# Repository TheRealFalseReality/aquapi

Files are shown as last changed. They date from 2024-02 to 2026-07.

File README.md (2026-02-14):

# [AquaPi for ESPHome](./)
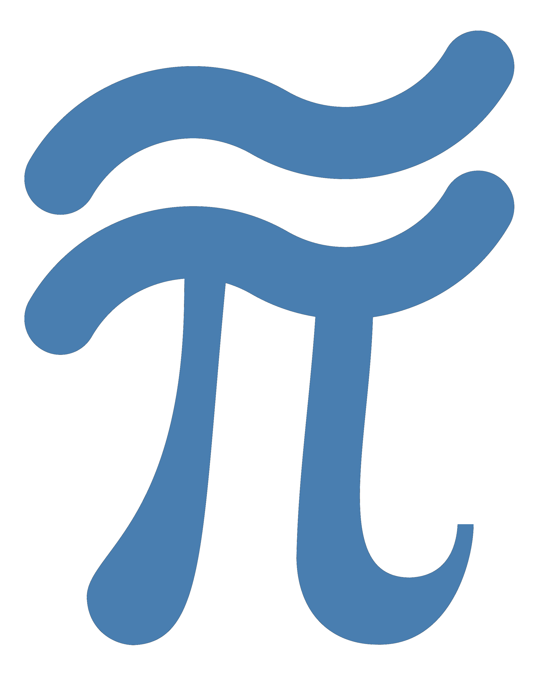
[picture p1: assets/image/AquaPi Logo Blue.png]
AquaPi Logo


The Aquarium meets the Smart Home! AquaPi brings powerful monitoring and automation to your aquarium setup using affordable [ESPHome](https://esphome.io/) devices and [Home Assistant](https://www.home-assistant.io/).  

**Open-source:** Freely accessible for anyone to use, modify, and contribute.  
**Modular and Customizable:** Expand the system to fit your specific needs and preferences.  
**Affordable:** A budget-friendly alternative to high-end monitoring solutions without compromising functionality.  
**Versatile:** Monitor and automate a wide range of vital water parameters such as pH, salinity, dissolved oxygen, and more.  

---

### **Quick Links**
- **[Install](https://therealfalsereality.github.io/aquapi/):** Navigate via the link, scroll to `Connect` to install via ESPHopme Web or use releases to install manually.
- **[Setup Guide](https://github.com/TheRealFalseReality/aquapi/wiki/Setup-AquaPi):** Start here for step-by-step instructions.
- **[Build It Yourself](https://github.com/TheRealFalseReality/aquapi/wiki/Build-It-Yourself-&-Spare-Parts):** Parts list and assembly guide.
- **[In-Depth Wiki](https://github.com/TheRealFalseReality/aquapi/wiki):** Calibration, sensor info, circuit diagrams, and more.
- **[Join the Discussion!](https://www.reef2reef.com/threads/aquapi-an-open-souce-aquarium-controller.1033171/)** Participate in the Reef2Reef forums!
- **[Buy AquaPi Now!](https://www.capitalcityaquatics.com/store/aquapi)** Purchase complete builds or modular components.

---

## Why AquaPi?

---

## Demo
## [**Try out the AquaPi Demo!**](https://aquapi.thefalsehome.duckdns.org/dashboard-aquariums)

<table>
  <tr>
    <td>
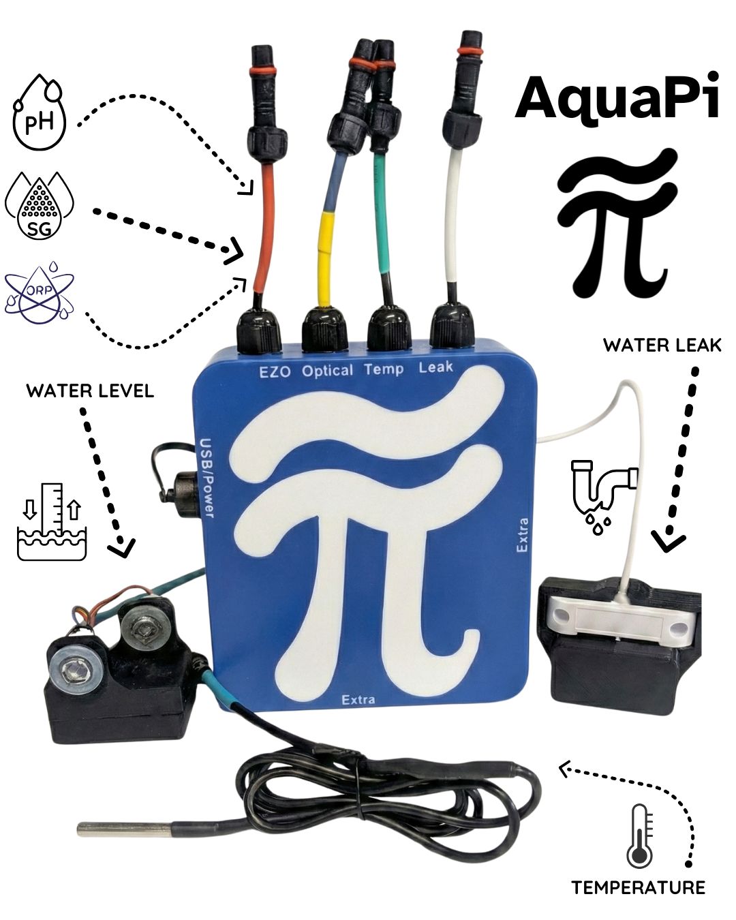
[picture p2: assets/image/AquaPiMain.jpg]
AquaPi Device
      
    </td>
    <td>
      AquaPi Setup Image
    </td>
  </tr>
</table>

---

## Key Features

- Comprehensive monitoring for **temperature**, **pH**, **salinity**, **dissolved oxygen**, and more using affordable Atlas Scientific EZO circuits.
- Seamless integration with **ESPHome** and **Home Assistant** for robust automation, visualization, and control.
- Expandable system to add new sensors, actuators, and custom automations tailored to your aquarium.

---

## Hardware Requirements

- **ESP32 DevKit:** A versatile microcontroller to power AquaPi.
- **Home Assistant Device:** A Raspberry Pi 3 or higher is recommended (the more RAM, the better).
  - Setup Home Assistant on your Raspberry Pi: [Get Raspberry Pi Imager](https://www.raspberrypi.com/software/)
- **Power Supply:** A reliable 5V 3A power source.

### Supported Sensors and Probes
#### **Temperature (Dallas DS18B20):**
- Waterproof thermistor capable of supporting multiple probes using an index-based configuration.
- [**Temperature Sensor Wiki**](https://github.com/TheRealFalseReality/aquapi/wiki/Dallas-Temperature-Sensor)

#### **Water Level:**
- Optical infrared liquid sensors with magnetic mounts.

#### **Water Leak Sensor:**
- Detects leaks with liquid detection sensors and magnetic mounting for flexibility.

#### **pH Monitoring (EZO-pH):**
- High-accuracy pH measurements with the EZO pH circuit, ISO 10523 compliant.  
- **Range:** 0-14 pH  
- **Recalibration Interval:** 1 year  
- **Probe Life Expectancy:** ~2.5+ years  
- [**pH Datasheet**](https://files.atlas-scientific.com/pH_EZO_Datasheet.pdf)

#### **Salinity Conductivity (EZO-EC):**
- Measures conductivity, TDS, salinity, and specific gravity with EZO EC circuit, ISO 7888 compliant.  
- **Range:** 0.07−500,000+ μS/cm  
- **Recalibration Interval:** ~10 years  
- **Probe Life Expectancy:** ~10 years  
- [**EC Datasheet**](https://files.atlas-scientific.com/EC_EZO_Datasheet.pdf)

#### **Dissolved Oxygen Monitoring (EZO-DO):**
- Accurate dissolved oxygen monitoring, suitable for many environments.  
- **Range:** 0.00-100 mg/L (0-350% saturation)  
- **Probe Life Expectancy:** ~4 years  
- [**DO Datasheet**](https://files.atlas-scientific.com/DO_EZO_Datasheet.pdf)

#### **Oxidation-Reduction Potential (EZO-ORP):**
- Measures the oxidation or reduction potential state in water.  
- **Range:** -2000mV to +2000mV  
- **Probe Life Expectancy:** ~2 years  
- [**ORP Datasheet**](https://files.atlas-scientific.com/ORP_EZO_Datasheet.pdf)

#### **Peristaltic Dosing Pump (EZO-PMP):**
- Dispenses liquids accurately for chemical or nutrient dosing.  
- **Flow Rate:** 0.5ml to 105ml/min  
- **Tube Size:** 5mm  
- **Head Height:** 8.1m (26.5')  
- [**Peristaltic Pump Datasheet**](https://files.atlas-scientific.com/EZO_PMP_Datasheet.pdf)

#### **Carbon Dioxide Air Monitoring (EZO-CO2):**
- Measures gaseous CO2 concentration.  
- **Range:** 0−10,000 ppm  
- **Life Expectancy:** ~5.5 years  
- [**CO2 Datasheet**](https://files.atlas-scientific.com/EZO_CO2_Datasheet.pdf)

### Additional Supported Sensors
- **Humidity:** [EZO-HUM Datasheet](https://files.atlas-scientific.com/EZO-HUM-Datasheet.pdf)  
- **RTD Temperature:** [EZO-RTD Datasheet](https://files.atlas-scientific.com/EZO_RTD_Datasheet.pdf)

### Circuit Diagram
For a detailed circuit diagram and wiring instructions, visit the [Wiki Circuit Page](https://github.com/TheRealFalseReality/aquapi/wiki/Circuit).

---

## Installation and Setup
### Setup Your Devices:
Follow the **[Setup Guide](https://github.com/TheRealFalseReality/aquapi/wiki/Setup-AquaPi)** for detailed step-by-step instructions for configuring your ESP32, connecting your sensors, and running AquaPi.

### Update Wirelessly:
Keep your AquaPi firmware up-to-date with **ESPHome** using the built-in Over-the-Air (OTA) update functionality. For details, see the [Update Guide](https://github.com/TheRealFalseReality/aquapi/wiki/Setup-AquaPi#update).

### Web Server Access:
Optionally, you can access AquaPi's web server for managing the device without Home Assistant. See the [Web Server Guide](https://github.com/TheRealFalseReality/aquapi/wiki/Setup-AquaPi#update) for more details.

---

## Expand and Customize AquaPi
AquaPi's modular design can be customized and expanded to meet your specific needs. For advanced configurations, see:  
- **[Blueprints](https://github.com/TheRealFalseReality/aquapi/wiki/Blueprints):** Automations to control other smart devices in Home Assistant.  
- **[Substitutions](https://github.com/TheRealFalseReality/aquapi/wiki/Substitutions):** Custom configuration variables for your specific setup.

---

## AquaPi AI: Your Intelligent Aquarium Assistant 🐠
### **[AquaPi AI](https://therealfalsereality.github.io/):** Level up your aquarium with AI!  
- **AI Compatibility Calculator:** Check fish compatibility instantly.  
- **Care Guides & Recommendations:** Get expert tank advice.  
- **Automation Scripts & Photo Analysis:** Automate your aquarium and analyze photos for optimized care.  

---

## Get Started Today!
- Check out the **[Setup Guide](https://github.com/TheRealFalseReality/aquapi/wiki/Setup-AquaPi)** to start using AquaPi.
- Enhance your aquarium monitoring with AquaPi’s powerful open-source, modular system!

---

made-for-esphome-white-on-black

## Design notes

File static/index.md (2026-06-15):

AquaPi Logo

The Aquarium meets the Smart Home! AquaPi brings powerful monitoring and automation to your aquarium setup using affordable [ESPHome](https://esphome.io/) devices and [Home Assistant](https://www.home-assistant.io/).  

**Open-source:** Freely accessible for anyone to use, modify, and contribute.  
**Modular and Customizable:** Expand the system to fit your specific needs and preferences.  
**Affordable:** A budget-friendly alternative to high-end monitoring solutions without compromising functionality.  
**Versatile:** Monitor and automate a wide range of vital water parameters such as pH, salinity, dissolved oxygen, and more.  

---

### **Quick Links**
- **[Setup Guide](https://github.com/TheRealFalseReality/aquapi/wiki/Setup-AquaPi):** Start here for step-by-step instructions.
- **[Build It Yourself](https://github.com/TheRealFalseReality/aquapi/wiki/Build-It-Yourself-&-Spare-Parts):** Parts list and assembly guide.
- **[In-Depth Wiki](https://github.com/TheRealFalseReality/aquapi/wiki):** Calibration, sensor info, circuit diagrams, and more.
- **[Join the Discussion!](https://www.reef2reef.com/threads/aquapi-an-open-souce-aquarium-controller.1033171/)** Participate in the Reef2Reef forums!
- **[Buy AquaPi Now!](https://www.capitalcityaquatics.com/store/aquapi)** Purchase complete builds or modular components.

---

## Why AquaPi?

---

## Demo
[**Try out the AquaPi Demo!**](https://www.capitalcityaquatics.com/store#storelivedemo)

<table>
  <tr>
    <td>
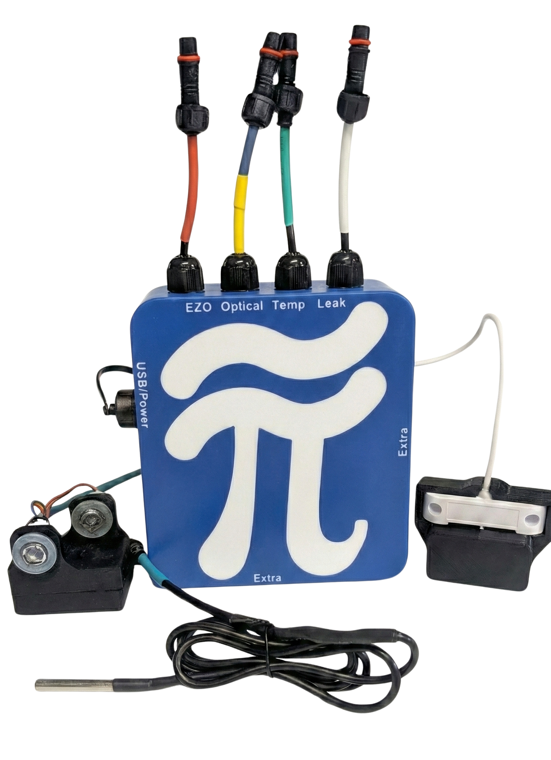
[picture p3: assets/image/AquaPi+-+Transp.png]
AquaPi Device
      
    </td>
    <td>
      AquaPi Setup Image
    </td>
  </tr>
</table>

---

## Install
**You can typically skip this as AquaPi comes pre-installed!**  
Use the button below to install the pre-built firmware directly to your device via USB from the browser.

### AquaPi Standard *(Inverted Optical - Legacy Optical Sensors)*
<esp-web-install-button manifest="firmware/aquapi-standard.manifest.json"></esp-web-install-button>

### AquaPi Optical *(Non-Inverted Optical - Newer Optical Sensors)*
<esp-web-install-button manifest="firmware/aquapi-standard.manifest.json"></esp-web-install-button>

<script type="module" src="https://unpkg.com/esp-web-tools@9.1.0/dist/web/install-button.js?module"></script>  

## Key Features

- Comprehensive monitoring for **temperature**, **pH**, **salinity**, **dissolved oxygen**, and more using affordable Atlas Scientific EZO circuits.
- Seamless integration with **ESPHome** and **Home Assistant** for robust automation, visualization, and control.
- Expandable system to add new sensors, actuators, and custom automations tailored to your aquarium.

---

## Hardware Requirements

- **ESP32 DevKit:** A versatile microcontroller to power AquaPi.
- **Home Assistant Device:** A Raspberry Pi 3 or higher is recommended (the more RAM, the better).
  - Setup Home Assistant on your Raspberry Pi: [Get Raspberry Pi Imager](https://www.raspberrypi.com/software/)
- **Power Supply:** A reliable 5V 3A power source.

### Supported Sensors and Probes
#### **Temperature (Dallas DS18B20):**
- Waterproof thermistor capable of supporting multiple probes using an index-based configuration.
- [**Temperature Sensor Wiki**](https://github.com/TheRealFalseReality/aquapi/wiki/Dallas-Temperature-Sensor)

#### **Water Level:**
- Optical infrared liquid sensors with magnetic mounts.

#### **Water Leak Sensor:**
- Detects leaks with liquid detection sensors and magnetic mounting for flexibility.

#### **pH Monitoring (EZO-pH):**
- High-accuracy pH measurements with the EZO pH circuit, ISO 10523 compliant.  
- **Range:** 0-14 pH  
- **Recalibration Interval:** 1 year  
- **Probe Life Expectancy:** ~2.5+ years  
- [**pH Datasheet**](https://files.atlas-scientific.com/pH_EZO_Datasheet.pdf)

#### **Salinity Conductivity (EZO-EC):**
- Measures conductivity, TDS, salinity, and specific gravity with EZO EC circuit, ISO 7888 compliant.  
- **Range:** 0.07−500,000+ μS/cm  
- **Recalibration Interval:** ~10 years  
- **Probe Life Expectancy:** ~10 years  
- [**EC Datasheet**](https://files.atlas-scientific.com/EC_EZO_Datasheet.pdf)

#### **Dissolved Oxygen Monitoring (EZO-DO):**
- Accurate dissolved oxygen monitoring, suitable for many environments.  
- **Range:** 0.00-100 mg/L (0-350% saturation)  
- **Probe Life Expectancy:** ~4 years  
- [**DO Datasheet**](https://files.atlas-scientific.com/DO_EZO_Datasheet.pdf)

#### **Oxidation-Reduction Potential (EZO-ORP):**
- Measures the oxidation or reduction potential state in water.  
- **Range:** -2000mV to +2000mV  
- **Probe Life Expectancy:** ~2 years  
- [**ORP Datasheet**](https://files.atlas-scientific.com/ORP_EZO_Datasheet.pdf)

#### **Peristaltic Dosing Pump (EZO-PMP):**
- Dispenses liquids accurately for chemical or nutrient dosing.  
- **Flow Rate:** 0.5ml to 105ml/min  
- **Tube Size:** 5mm  
- **Head Height:** 8.1m (26.5')  
- [**Peristaltic Pump Datasheet**](https://files.atlas-scientific.com/EZO_PMP_Datasheet.pdf)

#### **Carbon Dioxide Air Monitoring (EZO-CO2):**
- Measures gaseous CO2 concentration.  
- **Range:** 0−10,000 ppm  
- **Life Expectancy:** ~5.5 years  
- [**CO2 Datasheet**](https://files.atlas-scientific.com/EZO_CO2_Datasheet.pdf)

### Additional Supported Sensors
- **Humidity:** [EZO-HUM Datasheet](https://files.atlas-scientific.com/EZO-HUM-Datasheet.pdf)  
- **RTD Temperature:** [EZO-RTD Datasheet](https://files.atlas-scientific.com/EZO_RTD_Datasheet.pdf)

### Circuit Diagram
For a detailed circuit diagram and wiring instructions, visit the [Wiki Circuit Page](https://github.com/TheRealFalseReality/aquapi/wiki/Circuit).

---

## Installation and Setup
### Setup Your Devices:
Follow the **[Setup Guide](https://github.com/TheRealFalseReality/aquapi/wiki/Setup-AquaPi)** for detailed step-by-step instructions for configuring your ESP32, connecting your sensors, and running AquaPi.

### Update Wirelessly:
Keep your AquaPi firmware up-to-date with **ESPHome** using the built-in Over-the-Air (OTA) update functionality. For details, see the [Update Guide](https://github.com/TheRealFalseReality/aquapi/wiki/Setup-AquaPi#update).

### Web Server Access:
Optionally, you can access AquaPi's web server for managing the device without Home Assistant. See the [Web Server Guide](https://github.com/TheRealFalseReality/aquapi/wiki/Setup-AquaPi#update) for more details.

---

## Expand and Customize AquaPi
AquaPi's modular design can be customized and expanded to meet your specific needs. For advanced configurations, see:  
- **[Blueprints](https://github.com/TheRealFalseReality/aquapi/wiki/Blueprints):** Automations to control other smart devices in Home Assistant.  
- **[Substitutions](https://github.com/TheRealFalseReality/aquapi/wiki/Substitutions):** Custom configuration variables for your specific setup.

---

## AquaPi AI: Your Intelligent Aquarium Assistant 🐠
### **[AquaPi AI](https://therealfalsereality.github.io/):** Level up your aquarium with AI!  
- **AI Compatibility Calculator:** Check fish compatibility instantly.  
- **Care Guides & Recommendations:** Get expert tank advice.  
- **Automation Scripts & Photo Analysis:** Automate your aquarium and analyze photos for optimized care.  

---

## Get Started Today!
- Check out the **[Setup Guide](https://github.com/TheRealFalseReality/aquapi/wiki/Setup-AquaPi)** to start using AquaPi.
- Enhance your aquarium monitoring with AquaPi’s powerful open-source, modular system!

---

made-for-esphome-white-on-black

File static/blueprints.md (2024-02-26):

---
layout: page
title: Blueprints
permalink: /blueprints/
---
## [Blueprint Wiki](https://github.com/TheRealFalseReality/aquapi/wiki/Blueprints)
Click the link above to explore my Home Assistant scripts and automations for smart device control! I cover everything from lighting to water level management.  

### [Join the Community](https://community.home-assistant.io/u/therealfalsereality/activity/topics) to discuss improvements or make suggestions!

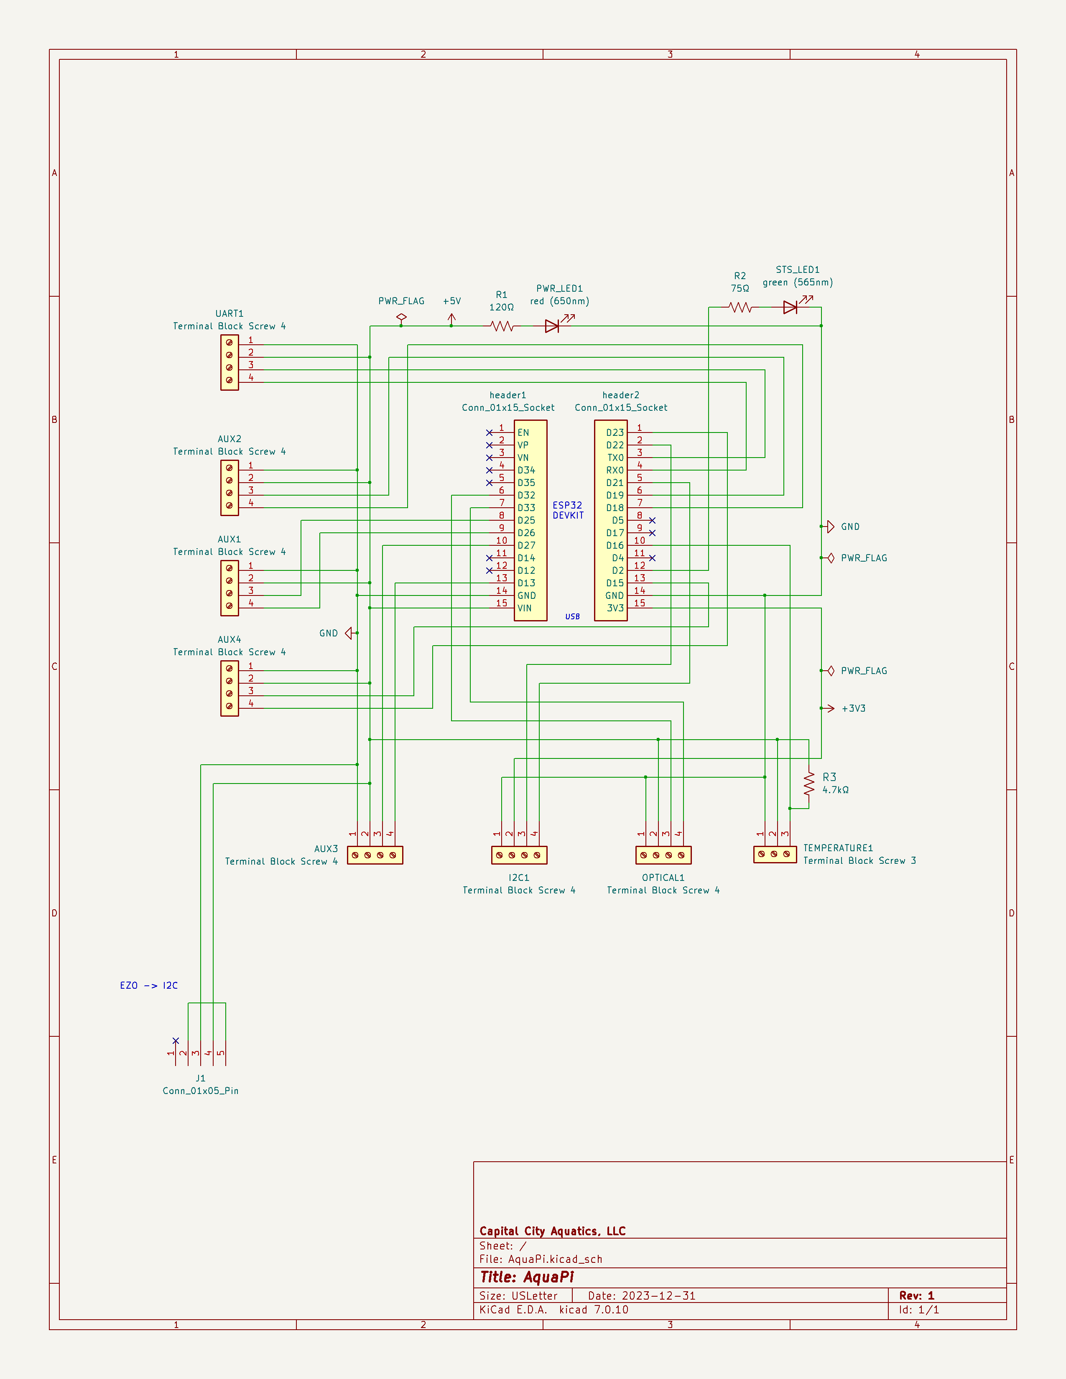
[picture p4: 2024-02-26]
assets/image/Schematic.png

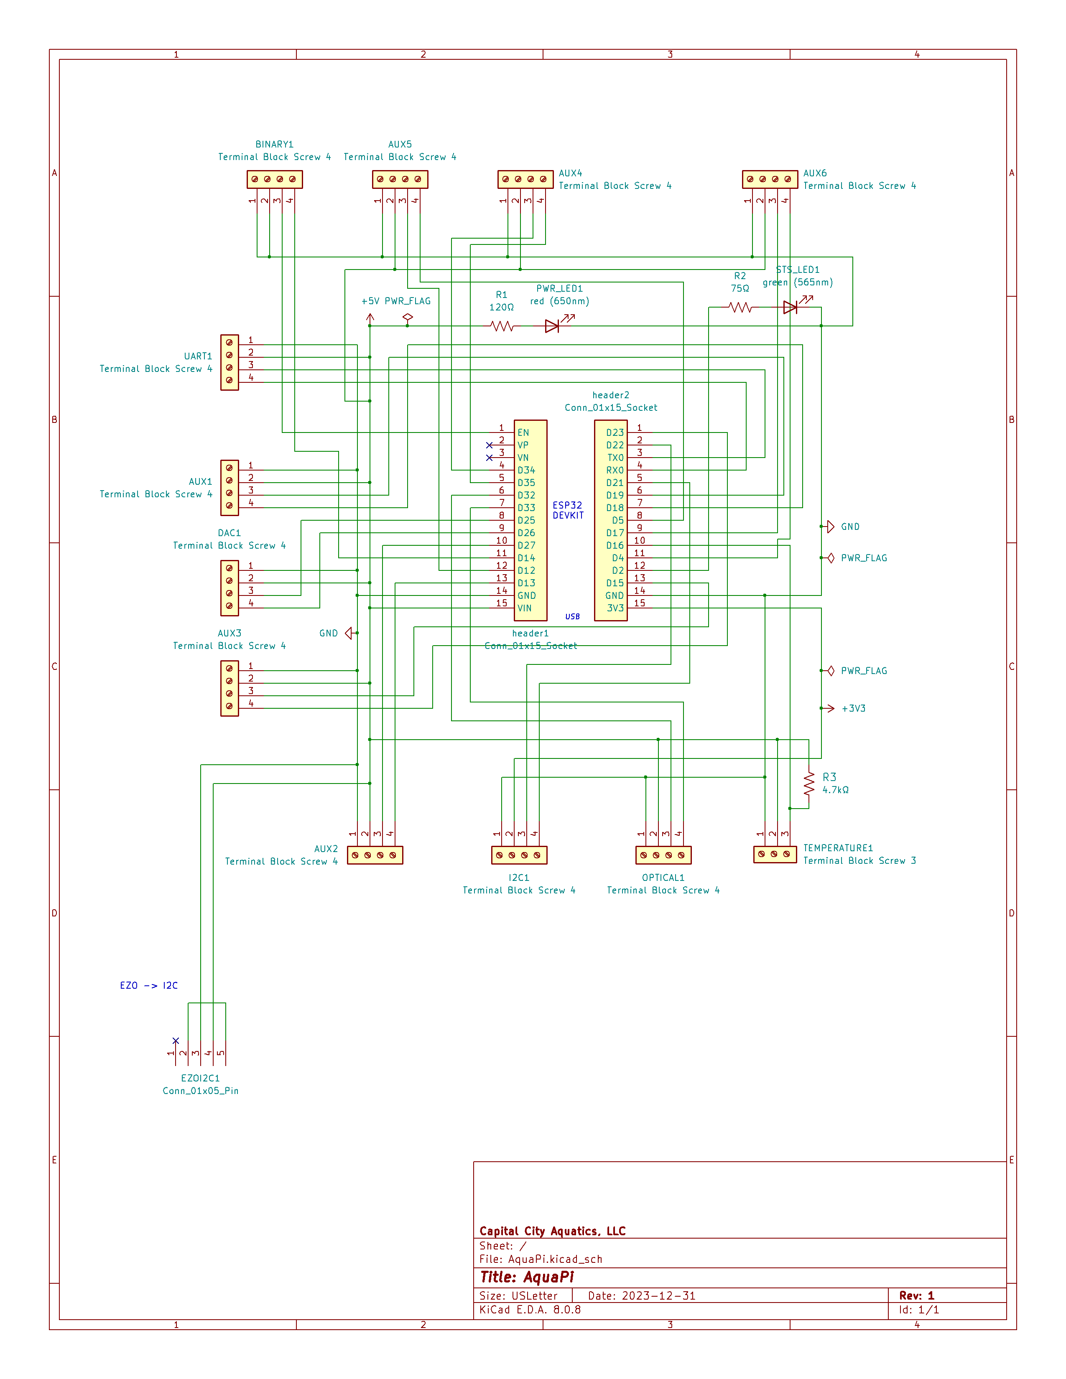
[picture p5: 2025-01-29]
assets/image/Schematicv2.png

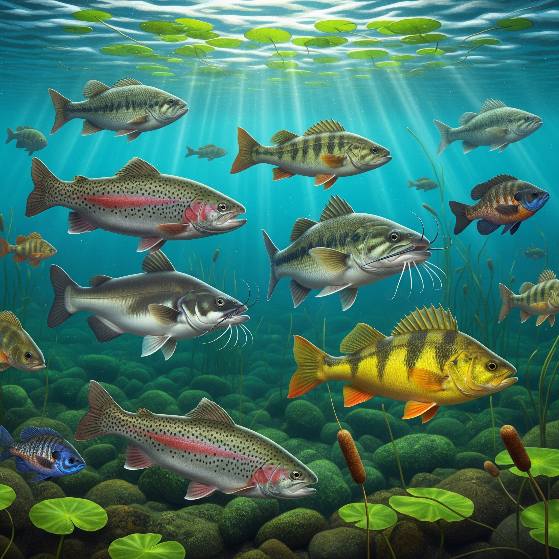
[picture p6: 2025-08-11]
assets/image/Gemini_Generated_Image_valg19valg19valg.jpg

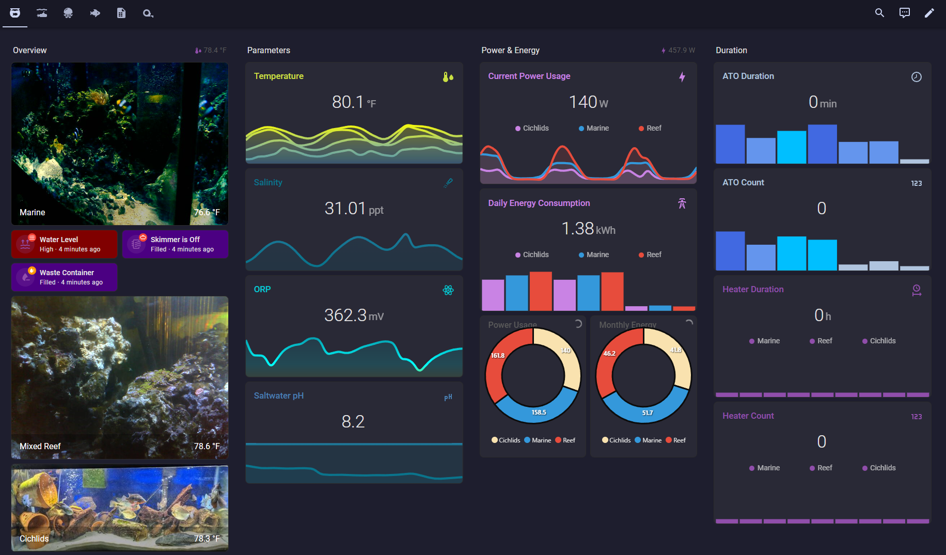
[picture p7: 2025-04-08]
assets/image/Screenshot 2024-10-15 120850.png

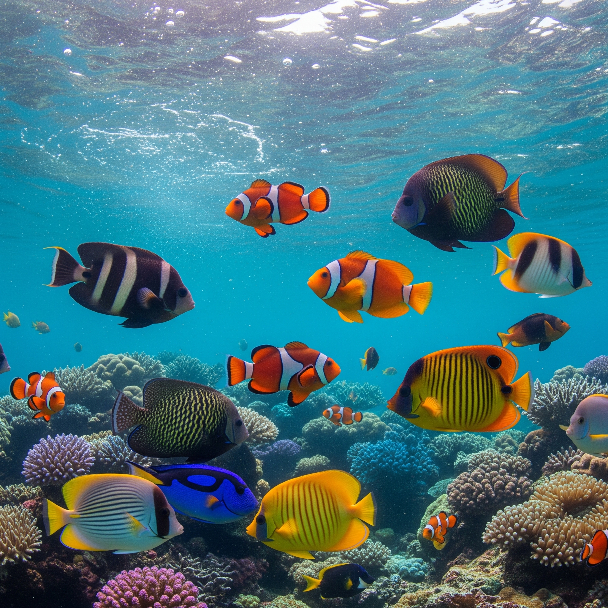
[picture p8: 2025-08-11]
assets/image/Gemini_Generated_Image_w0boutw0boutw0bo.jpg

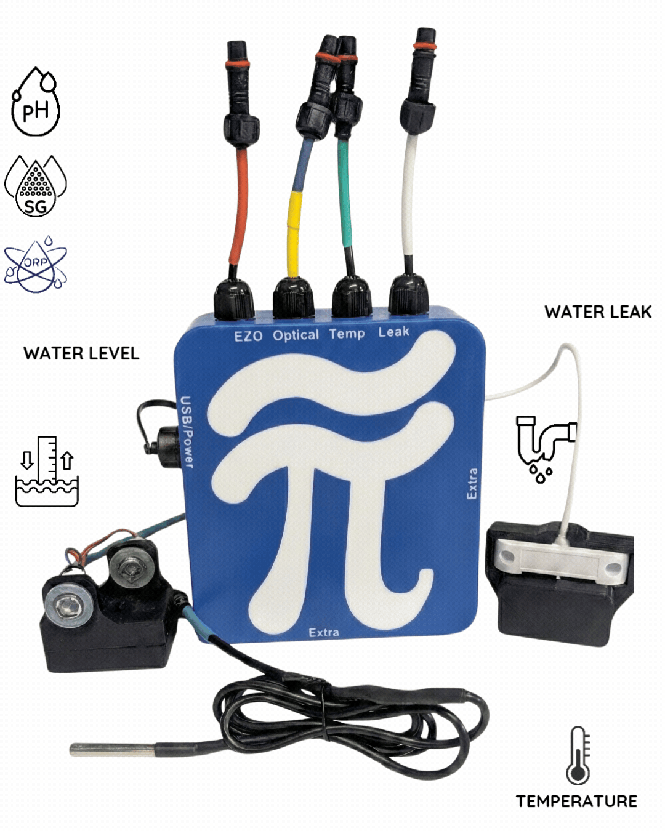
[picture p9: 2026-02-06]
assets/image/AquaPiMain.gif

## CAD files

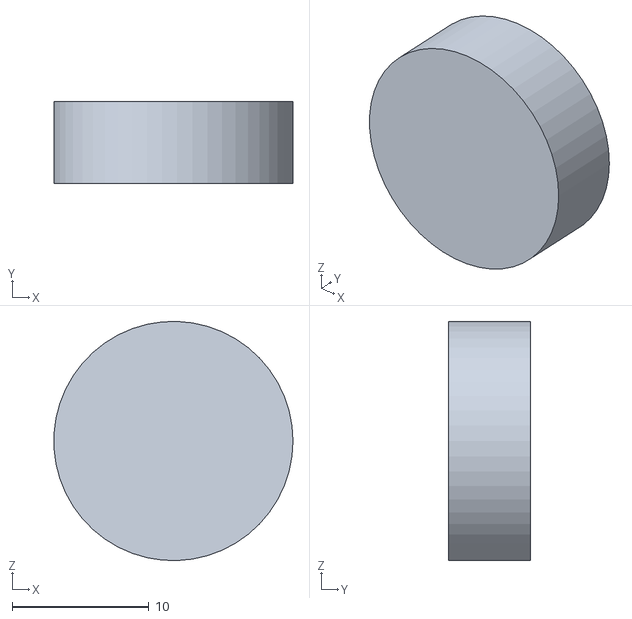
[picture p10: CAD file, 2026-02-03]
assets/STLModels/AquaPiCase/AquaPi Case - Plug2.stl
17.5 x 6.00 x 17.5

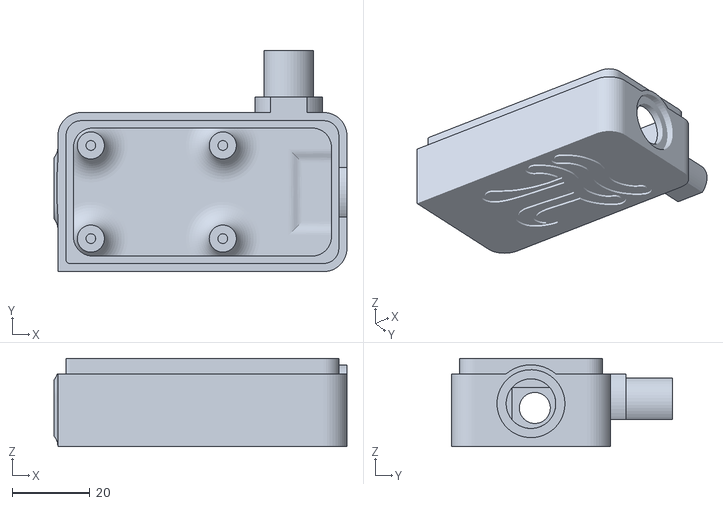
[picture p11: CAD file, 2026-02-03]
assets/STLModels/EZOCase/EZOBoard Case rev2 v11.stl
75.5 x 57.0 x 22.8

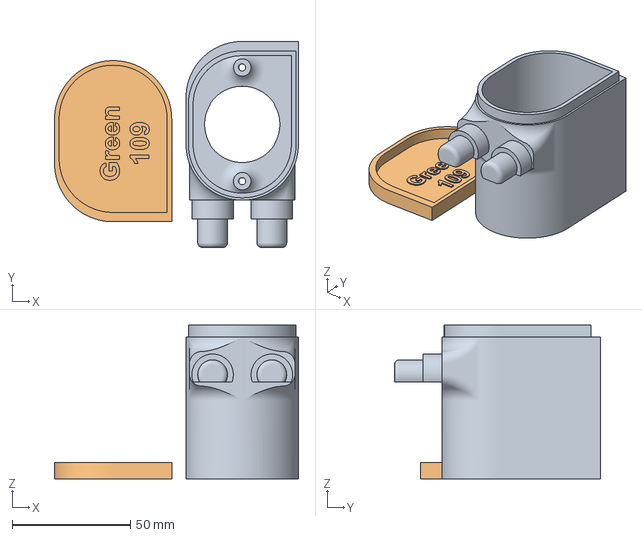
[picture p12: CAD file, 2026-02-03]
assets/STLModels/EZOPump/AquaPi Pump Case - Green.3mf
103.0 x 87.0 x 65.0 mm
AquaPi Pump Case v25.stl
AquaPi Pump Lid v25.stl

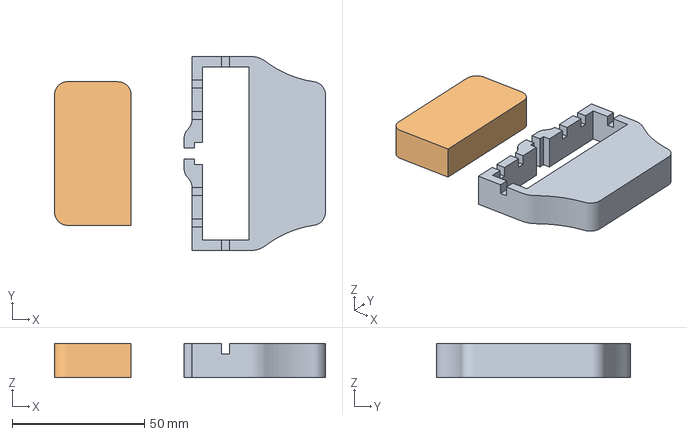
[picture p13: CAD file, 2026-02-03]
assets/STLModels/LeakSensor/Leak Sensor - Mount.3mf
102.5 x 73.5 x 13.0 mm
Leak Sensor v14 - Base.stl
Leak Sensor - Mag v13.stl

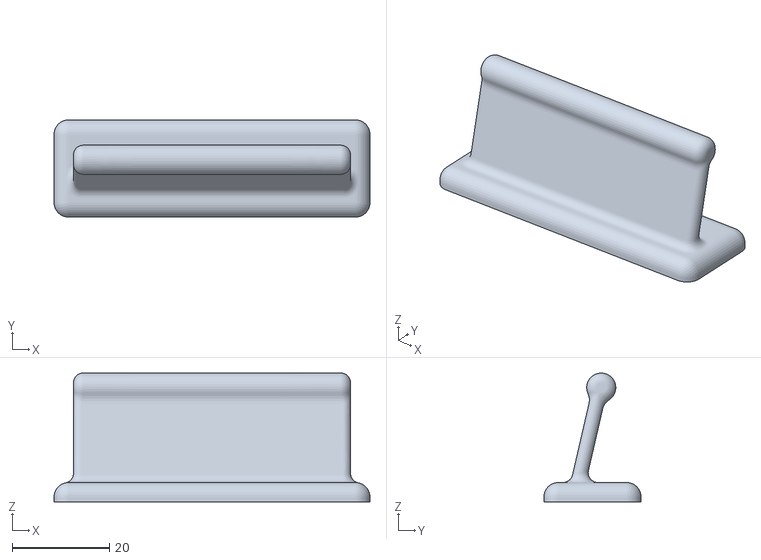
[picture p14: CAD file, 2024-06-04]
assets/STLModels/misc/Handle v2.stl
65.0 x 20.0 x 26.5

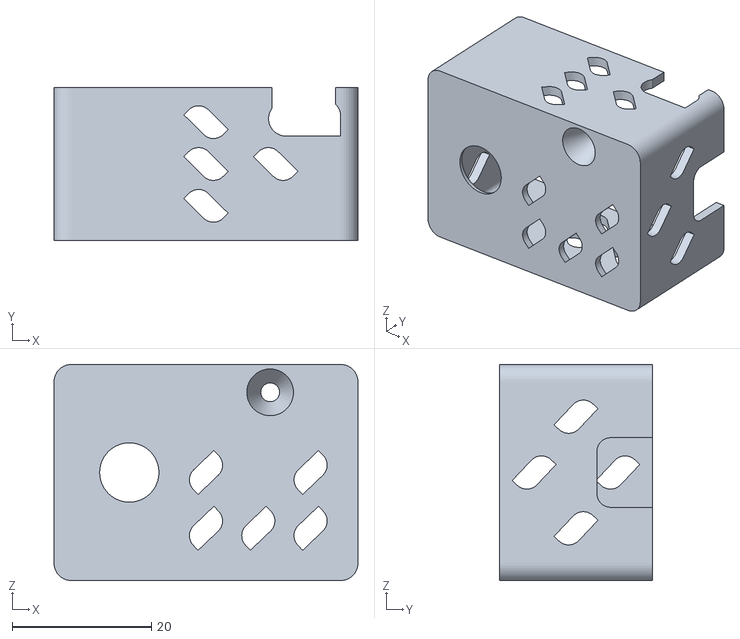
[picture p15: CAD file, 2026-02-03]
assets/STLModels/SnapCam/esp32Cam - Case v35.stl
43.6 x 22.0 x 31.0

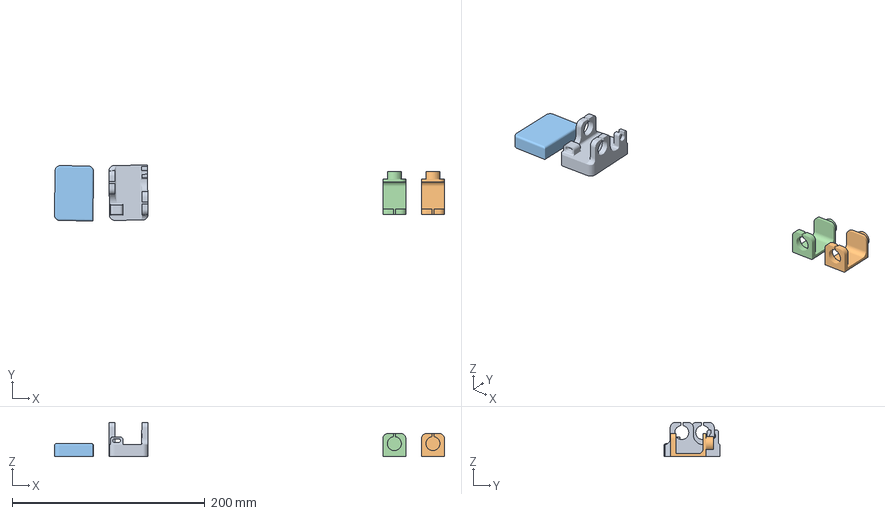
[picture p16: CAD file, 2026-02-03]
assets/STLModels/WaterLevelBracket/WaterLevelHolder.3mf
404.5 x 57.9 x 35.5 mm
OpticalBracket_Holder.stl
OpticalBracket Extender.stl x 2
OpticalBracket_Back.stl

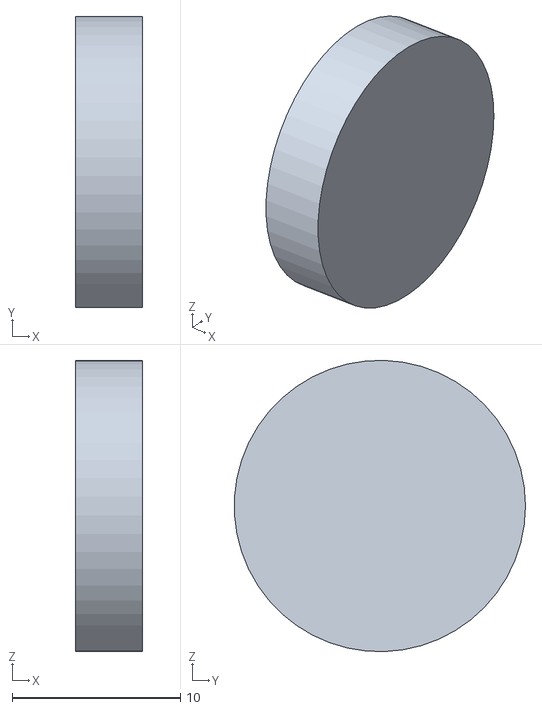
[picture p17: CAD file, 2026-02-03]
assets/STLModels/AquaPiCase/AquaPi Case - Plug1.stl
4.00 x 17.3 x 17.3

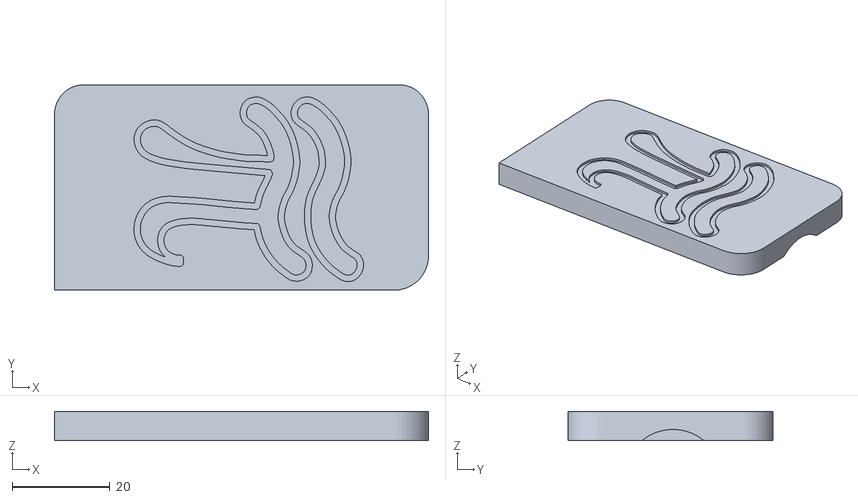
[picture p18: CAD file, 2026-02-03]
assets/STLModels/EZOCase/EZOBoard Lid rev2 v14.stl
76.5 x 42.0 x 6.00

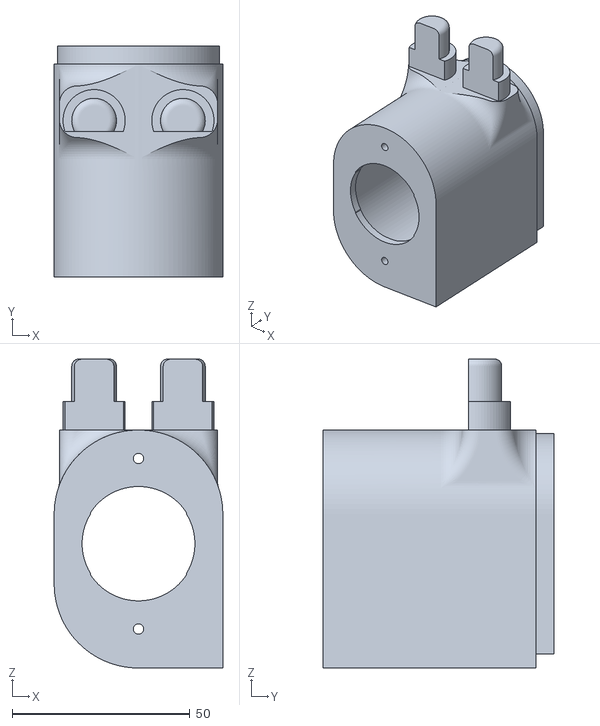
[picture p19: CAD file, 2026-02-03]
assets/STLModels/EZOPump/AquaPi Pump Case v25.stl
47.5 x 65.0 x 87.0

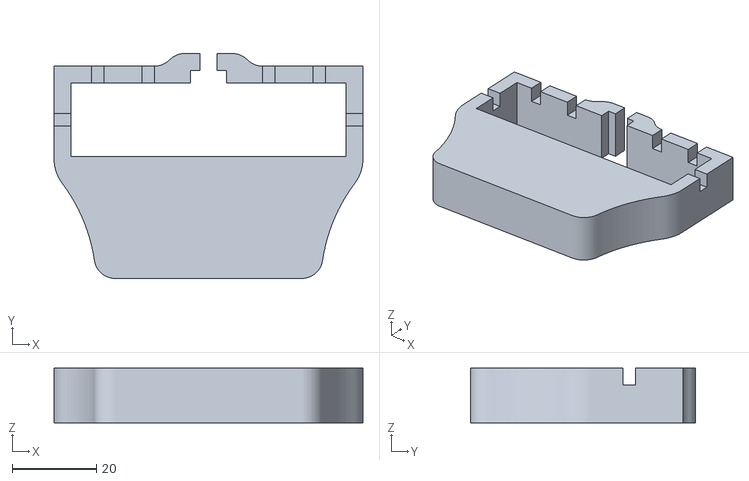
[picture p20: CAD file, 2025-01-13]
assets/STLModels/LeakSensor/Leak Sensor v14 - Base.stl
73.5 x 53.5 x 13.0

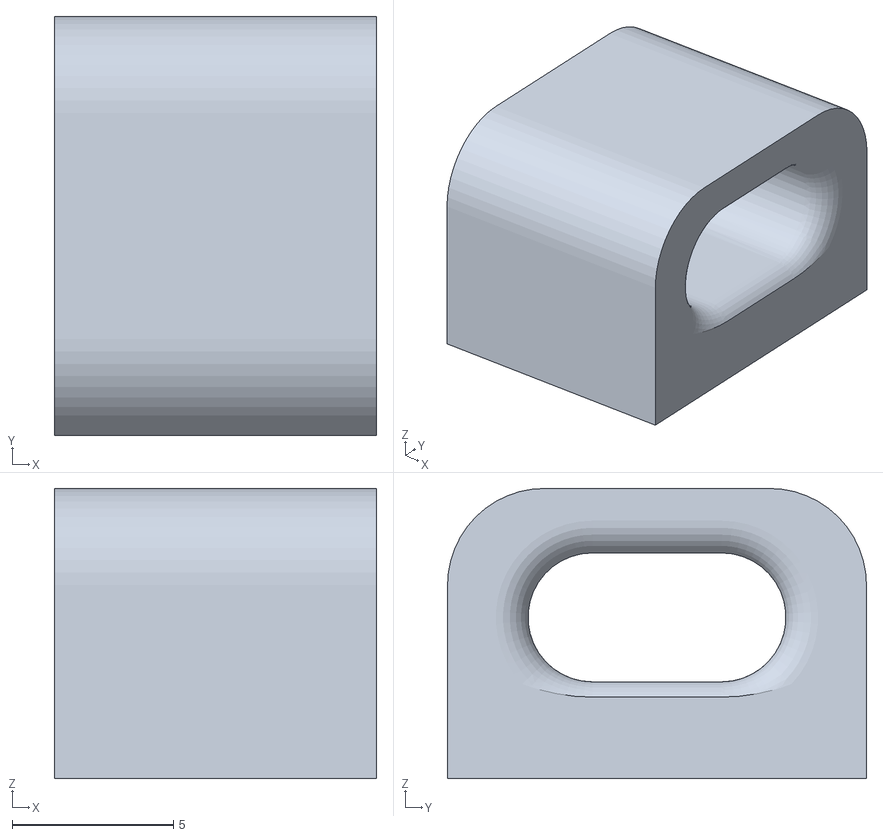
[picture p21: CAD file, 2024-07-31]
assets/STLModels/SnapCam/BallMount - ZipTie v9.stl
10.0 x 13.0 x 9.00

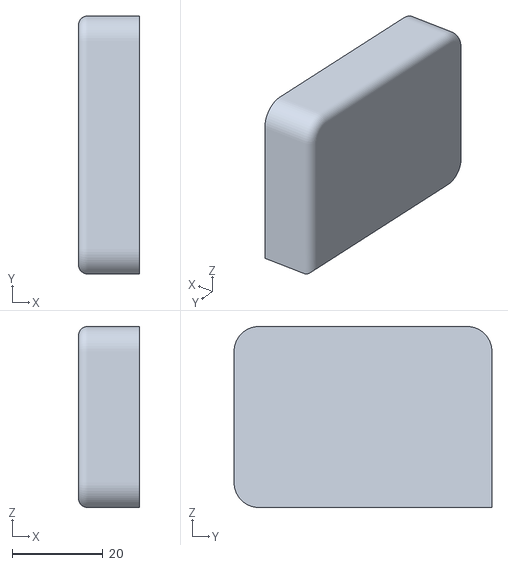
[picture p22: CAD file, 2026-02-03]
assets/STLModels/WaterLevelBracket/OpticalBracket_Back.stl
13.5 x 57.0 x 40.0

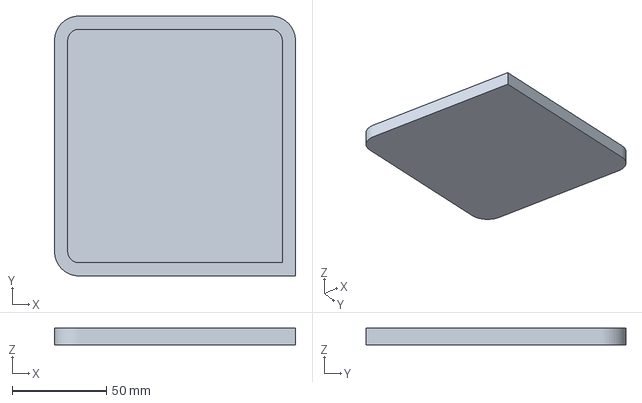
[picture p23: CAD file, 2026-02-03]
assets/STLModels/AquaPiCase/AquaPi Case - Lid MC.3mf
128.0 x 138.0 x 9.00 mm

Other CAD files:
assets/STLModels/EZOCase/EZOBoard rev2.3mf
assets/STLModels/EZOPump/AquaPi Pump Case - Red.3mf
assets/STLModels/LeakSensor/Leak Sensor - Mag v13.stl
assets/STLModels/SnapCam/BallMount v9.stl
assets/STLModels/AquaPiCase/AquaPi Case - Base v58.stl
assets/STLModels/AquaPiCase/AquaPi Case - Lid v45.stl
assets/STLModels/AquaPiCase/AquaPi Mount - Base v25.stl
assets/STLModels/AquaPiCase/AquaPi Mount - Hanger v25.stl
assets/STLModels/EZOPump/AquaPi Pump Lid - Green v25.stl
assets/STLModels/EZOPump/AquaPi Pump Lid - Red v26.stl
assets/STLModels/SnapCam/esp32Cam - Lid v32.stl
assets/STLModels/WaterLevelBracket/OpticalBracket Extender.stl
assets/STLModels/WaterLevelBracket/OpticalBracket_Holder.stl

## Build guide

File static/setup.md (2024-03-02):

---
layout: page
title: Setup
permalink: /setup/
---
## Install
**You can typically skip this as AquaPi comes pre-installed!**  

### Easy
Go back to [**Home**](https://therealfalsereality.github.io/aquapi/) and scroll down to ***Install*** and click the ***Connect*** button.  

### Releases .bin
1. Download latest .bin from [**Releases**](https://github.com/TheRealFalseReality/aquapi/releases)  
2. Install via [**ESPHome - Web**](https://web.esphome.io/)  

## Setup AquaPi
Follow link below for guide:  
<a href="https://github.com/TheRealFalseReality/aquapi/wiki/Setup-AquaPi" target="_blank"><b>Setup Guide</b></a>

## Home Assistant & AquaPi
UI


### [Blueprints](https://github.com/TheRealFalseReality/aquapi/wiki/Blueprints)
There are scripts and automations I created to control other devices within Home Assistant. Click the link above to view them all!

### Home Assistand Dashboard & Card Examples
If you want to try some of the Dashboard or Cards I use, follow the link below. You may need addtional integrations or custom cards for some of them!  
<a href="https://github.com/TheRealFalseReality/aquapi/tree/187430491ea4f73817521e7c685bf6fce8c85b59/Home%20Assistant%20Cards%20%26%20Templates" target="_blank"><b>Example HomeAssistant Cards & Templates</b></a>

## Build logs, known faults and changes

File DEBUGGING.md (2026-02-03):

# AquaPi Debugging Standards

This document establishes debugging standards and best practices for the AquaPi project.

## Table of Contents
- [Logging Standards](#logging-standards)
- [I2C Sensor Detection](#i2c-sensor-detection)
- [Error Handling](#error-handling)
- [Debug Components](#debug-components)
- [Troubleshooting Guide](#troubleshooting-guide)

## Logging Standards

### Log Levels

Use appropriate log levels for different types of messages:

| Level | Macro | When to Use | Example |
|---|---|---|---|
| **DEBUG** | `ESP_LOGD()` | General debugging information, detailed trace | `ESP_LOGD("ezo_ph", "Reading pH value: %.2f", value);` |
| **INFO** | `ESP_LOGI()` | Important state changes, confirmations | `ESP_LOGI("ezo_ph", "pH sensor initialized successfully");` |
| **WARNING** | `ESP_LOGW()` | Issues that don't stop execution | `ESP_LOGW("ezo_ph", "pH sensor not detected at address 99");` |
| **ERROR** | `ESP_LOGE()` | Errors affecting functionality | `ESP_LOGE("i2c", "I2C bus communication failed");` |
| **VERBOSE** | `ESP_LOGV()` | Extremely detailed trace (enable in config) | `ESP_LOGV("ezo_ph", "Sending command: %s", cmd);` |

### Log Message Format

Always follow this format for consistency:

```cpp
ESP_LOG[LEVEL]("component_name", "Message with context and data");
```

**Best Practices:**
- Use descriptive component names (e.g., "ezo_ph", "i2c_detection", "debug")
- Include relevant data: addresses, values, states
- Make messages actionable (help users understand what to do)
- Use format specifiers correctly: `%d` (int), `%f` (float), `%s` (string), `0x%02X` (hex)

**Examples:**

```cpp
// Good - includes context and data
ESP_LOGD("ezo_ph", "pH reading: %.2f at address 0x%02X", value, address);
ESP_LOGI("i2c_detection", "Found %d I2C devices on bus", count);
ESP_LOGW("ezo_ec", "EC sensor not responding at address 100");

// Bad - lacks context
ESP_LOGD("sensor", "Got value");
ESP_LOGW("main", "Error");
```

## I2C Sensor Detection

### Using ESPHome's Native I2C API

**Important:** Use ESPHome's native I2C API instead of the Arduino Wire library. ESPHome's I2C component and Arduino's Wire library cannot coexist on the same bus - they conflict for hardware control.

**Correct approach - ESPHome I2C API:**

```cpp
// Check if I2C device is present using ESPHome's API
uint8_t address = 0x63;  // 99 decimal = 0x63 hex
esphome::i2c::ErrorCode err = id(bus_a)->write(address, nullptr, 0);
if (err == esphome::i2c::ERROR_OK) {
  // Sensor is present
  ESP_LOGI("ezo_ph", "pH sensor detected at address 99 (0x63)");
  id(ph_ezo).send_custom("R");
} else {
  ESP_LOGW("ezo_ph", "pH sensor not detected at address 99 (0x63)");
}
```

**Helper function pattern (recommended):**

```cpp
// Define a reusable helper function in lambda
auto check_i2c_device = [](uint8_t address) -> bool {
  esphome::i2c::ErrorCode err = id(bus_a)->write(address, nullptr, 0);
  return (err == esphome::i2c::ERROR_OK);
};

// Use it multiple times
if (check_i2c_device(0x63)) {
  ESP_LOGI("ezo_ph", "pH sensor detected");
}
```

**Note:** Writing nullptr (0 bytes) is a standard I2C probe technique that checks if a device ACKs its address without sending any data.

### I2C Address Reference

| Sensor | Decimal Address | Hex Address | Default Variable |
|---|---|---|---|
| EZO DO | 97 | 0x61 | `addDO` |
| EZO ORP | 98 | 0x62 | `addORP` |
| EZO pH | 99 | 0x63 | `addPH` |
| EZO EC | 100 | 0x64 | `addEC` |
| EZO RTD | 102 | 0x66 | `addRTD` |
| EZO PMP (White) | 103 | 0x67 | `addPMP_white` |
| EZO PMP (Yellow) | 104 | 0x68 | `addPMP_yellow` |
| EZO CO2 | 105 | 0x69 | `addCO2` |
| EZO PMP (Blue) | 106 | 0x6A | `addPMP_blue` |
| EZO PMP (Red) | 108 | 0x6C | `addPMP_red` |
| EZO PMP (Green) | 109 | 0x6D | `addPMP_green` |
| EZO PMP (Orange) | 110 | 0x6E | `addPMP_orange` |
| EZO HUM | 111 | 0x6F | `addHUM` |

### Detection Components

The project now includes dedicated I2C detection components in `common/i2c_detection.yaml`:

1. **Individual Sensor Detection** - Binary sensors for each EZO device
2. **I2C Device Counter** - Total number of connected devices
3. **I2C Bus Status** - Overall bus health
4. **Address List** - All detected addresses
5. **Manual Scan Button** - Force a bus scan

## Error Handling

### Check Before Processing

Always validate data before use:

```cpp
// Check if sensor is connected using ESPHome I2C API
esphome::i2c::ErrorCode err = id(bus_a)->write(0x63, nullptr, 0);
if (err != esphome::i2c::ERROR_OK) {
  ESP_LOGW("ezo_ph", "pH sensor not detected, skipping read");
  return NAN;  // Return NAN for numeric sensors
}

// Check for null/invalid values
std::string str = id(raw_value_ec).state;
if (str.empty()) {
  ESP_LOGW("ezo_ec", "No data from EC sensor");
  return NAN;
}

// Validate parsed data
std::vector<std::string> v = parse_csv(str);
if (v.size() != 4) {
  ESP_LOGW("ezo_ec", "Unexpected data format: expected 4 values, got %d", v.size());
  return NAN;
}
```

### Graceful Degradation

The system should continue operating even when sensors are missing:

```cpp
lambda: |-
  // Attempt to read sensor
  esphome::i2c::ErrorCode err = id(bus_a)->write(0x63, nullptr, 0);
  if (err == esphome::i2c::ERROR_OK) {
    id(ph_ezo).send_custom("R");
    return true;  // Success
  } else {
    // Sensor missing, log but don't crash
    ESP_LOGW("ezo_ph", "pH sensor not available");
    return false;  // Failure, but system continues
  }
```

## Debug Components

### Available Debug Tools

1. **Debug Module** (`common/debug.yaml`):
   - Heap memory monitoring
   - Loop time tracking
   - Memory usage percentage
   - I2C health score
   - System health status
   - ESPHome version
   - Reset reason tracking

2. **I2C Detection Module** (`common/i2c_detection.yaml`):
   - Individual sensor detection binary sensors
   - Total device counter
   - I2C bus status
   - List of detected addresses
   - Manual scan button

3. **Debug Buttons**:
   - **Memory Report** - Detailed memory statistics
   - **I2C Report** - Complete I2C bus scan with device identification

### Using Debug Components

#### Monitor Memory Usage

Watch for memory leaks or high usage:

```yaml
# In automation or script
- if:
    condition:
      lambda: 'return id(memory_usage_percent).state > 80.0;'
    then:
      - logger.log:
          level: WARN
          message: "High memory usage detected!"
```

#### Check I2C Health

Monitor I2C bus reliability:

```yaml
# Check I2C health before critical operations
- if:
    condition:
      lambda: 'return id(i2c_health_score).state < 50.0;'
    then:
      - logger.log:
          level: ERROR
          message: "I2C bus degraded - check connections"
```

#### Manual Diagnostics

Use the debug buttons in Home Assistant or the web interface:
1. Press "Debug - I2C Report" to see all connected devices
2. Press "Debug - Memory Report" to check system resources
3. Press "I2C Scan Now" to refresh sensor detection

## Troubleshooting Guide

### Issue: No I2C Devices Detected

**Symptoms:**
- "I2C Devices Connected" shows 0
- All EZO sensor detection shows "off"

**Solutions:**
1. Check physical connections (SDA=GPIO21, SCL=GPIO22)
2. Verify EZO circuits are powered (green LED)
3. Run "I2C Scan Now" button
4. Check logs for I2C errors: `ESP_LOGE("i2c", ...)`
5. Verify I2C pullup resistors (usually built-in on EZO circuits)

### Issue: Specific Sensor Not Detected

**Symptoms:**
- Other sensors work, but one doesn't appear
- Sensor binary sensor shows "off"

**Solutions:**
1. Verify the sensor's I2C address (might have been changed)
2. Check if sensor LED is on (power issue)
3. Try the sensor alone on the bus (address conflict?)
4. Use "Debug - I2C Report" to see actual addresses
5. Check for loose wiring on that specific sensor

### Issue: High Memory Usage

**Symptoms:**
- "Memory Usage Percent" > 80%
- System becomes unstable or crashes
- "System Health Status" shows "WARNING" or "CRITICAL"

**Solutions:**
1. Press "Debug - Memory Report" to see details
2. Reduce update intervals in sensor configs
3. Disable unused sensors or components
4. Check for memory leaks in custom lambda code
5. Consider reducing log verbosity

### Issue: I2C Communication Errors

**Symptoms:**
- Sensors intermittently stop responding
- "I2C Health Score" is low (<50%)
- Seeing "NACK" or timeout errors in logs

**Solutions:**
1. Check wire quality and length (keep under 1 meter for high reliability)
2. Add external pullup resistors (2.2kΩ-4.7kΩ) to SDA and SCL if bus is long
3. Reduce update frequency to give devices more time
4. Check for ground loops or power supply noise
5. Try reducing I2C bus speed (add to device_base.yaml):
   ```yaml
   i2c:
     sda: ${sdaPin}
     scl: ${sclPin}
     scan: true
     id: bus_a
     frequency: 50kHz  # Default is 100kHz
   ```

### Issue: Sensor Shows "Unknown" or NAN

**Symptoms:**
- Sensor detection shows "on" but no readings
- Values show as "Unknown" or "NAN"

**Solutions:**
1. Check sensor calibration
2. Verify sensor is in appropriate medium (water for aquatic sensors)
3. Check command syntax in logs
4. Try manual read using sensor's read button
5. Send "Status" command to check sensor state
6. Review sensor-specific troubleshooting in Atlas Scientific documentation

### Issue: EZO Sensor "read error" Messages

**Symptoms:**
- Log shows messages like `[E][ezo.sensor:088]: read error` or `[E][ezo-pmp:111]: read error`
- These errors appear every 60 seconds (at sensor update interval)
- Sensor is configured but not physically connected

**Understanding the Error:**
These errors occur when ESPHome tries to read from a sensor at its configured `update_interval`, but the sensor is not present on the I2C bus. The cryptic error code (e.g., `:088:`, `:111:`) is an internal ESPHome component line number, not helpful for troubleshooting.

**Solutions:**

1. **If the sensor is not installed and you don't plan to use it:**
   
   Disable automatic updates by setting the update interval to "never" in your substitutions:
   
   ```yaml
   substitutions:
     update_ph: "never"          # Disable pH sensor updates
     update_ec: "never"          # Disable EC sensor updates
     update_orp: "never"         # Disable ORP sensor updates
     update_do: "never"          # Disable DO sensor updates
     update_pmp_white: "never"   # Disable White pump updates
     update_pmp_green: "never"   # Disable Green pump updates
     update_pmp_red: "never"     # Disable Red pump updates
   ```
   
   You can also use very long intervals to effectively disable updates:
   
   ```yaml
   substitutions:
     update_ph: "365days"        # Only update once per year (effectively disabled)
   ```

2. **If you plan to install the sensor later:**
   
   Set the update interval to "never" temporarily, then change it back when the sensor is installed.

3. **Check the helpful detection warnings:**
   
   The system now logs user-friendly warnings for missing sensors every 60 seconds:
   
   ```
   [W][ezo_detection:xxx] No pH (0x63) sensor detected! If not in use, set 'update_ph: "never"' in substitutions to disable updates and avoid errors.
   ```
   
   These messages tell you exactly which sensor is missing and how to disable it.

4. **Use the I2C Detection sensors:**
   
   Check the "EZO XX Sensor Detected" binary sensors in Home Assistant to see which sensors are found. Only enable update intervals for detected sensors.

**Technical Details:**

EZO sensors (pH, EC, ORP, DO, CO2, RTD, HUM) and EZO pumps now use a button-based update pattern with detection checks:
- The button checks if the sensor is present before attempting to read
- If the sensor is missing, a friendly warning is logged (e.g., "No pH sensor detected at address: 99!!")
- If the sensor is present, the read proceeds normally

This prevents the cryptic "read error" messages when using button-triggered updates. However, if the sensor's `update_interval` is set (not "never"), ESPHome will also try automatic updates which will generate errors if the sensor is missing.

**Recommended Configuration:**

For sensors that may not always be connected:
```yaml
substitutions:
  update_ph: "60s"           # Sensor update interval (can set to "never")
  update_button_ph: "60s"    # Button-triggered update interval (has detection check)
```

- Set `update_ph: "never"` to disable automatic sensor reads
- Keep `update_button_ph: "60s"` to enable button-triggered reads with detection checking
- This gives you clean logs while still allowing on-demand reads when the sensor is connected

## Best Practices Summary

✅ **DO:**
- Use ESPHome's native I2C API (`id(bus_a)->write()`) for sensor detection
- Log with appropriate levels (DEBUG, INFO, WARN, ERROR)
- Include context in all log messages
- Check for null/NAN before processing data
- Monitor memory and I2C health regularly
- Test with sensors disconnected
- Provide graceful fallbacks for missing sensors

❌ **DON'T:**
- Use Arduino Wire library (conflicts with ESPHome's I2C component)
- Log at ERROR level for expected conditions (like missing optional sensors)
- Assume sensors are always present
- Ignore NAN or null values
- Skip validation of parsed data
- Remove error checking to "simplify" code

## Additional Resources

- ESPHome I2C Bus Documentation: https://esphome.io/components/i2c.html
- Atlas Scientific EZO Documentation: `Atlas EZO docs/` directory in repository root
- ESPHome Logging: https://esphome.io/components/logger.html
- ESPHome Debug Component: https://esphome.io/components/debug.html

## Support

For issues or questions:
1. Check the logs first (enable VERBOSE if needed)
2. Run diagnostic buttons (Memory Report, I2C Report)
3. Check this debugging guide
4. Review GitHub issues: https://github.com/TheRealFalseReality/aquapi/issues
5. Consult Atlas Scientific support for sensor-specific issues

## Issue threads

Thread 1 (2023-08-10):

Finish Calibration Firmware

TheRealFalseReality, 2023-08-10:
I need to make the firmware with calibration commands and more frequent EZO probes reads

TheRealFalseReality, 2023-08-24:
EZO Calibration configs should be good to go!

Closed 2023-08-24.

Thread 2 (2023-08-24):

Dallas Temp Probe Calibration from Frontend

TheRealFalseReality, 2023-08-24:
Want to add the ability to calibrate the Dallas temp probes as needed.

TheRealFalseReality, 2023-08-26:
The only thing I can get to a variable for the True value is a substutution, which I do not know how to change via the frontend. I can't insert any lambdas to insert the state from another number sensor, it expects a float. I am putting this on pause.

This works for now:
```
substitutions:
  # calibration variables
  # calibration at 0C - Ice Water
  cal_0: "0.0"
  # calibration at 100C - Boiling Water
  cal_100: "100.0"

sensor:
 # Temperature Probes 1
  - platform: dallas
    id: temp_1
    icon: mdi:thermometer-lines
    index: 0
    name: "Temperature"
    filters:
      - calibrate_linear:
          method: least_squares
          datapoints:
            - 0.0 -> ${cal_0}
            - 100.0 -> ${cal_100}
```

Won't work:
```
number:
  # Calibration Temp. at 0C - Ice Bath
  - platform: template
    name: "Calibration Temp. at 0C - Ice Bath"
    id: cal_0
    icon: mdi:snowflake-alert
    optimistic: true
    min_value: -10.0
    max_value: 10.0
    step: .1
    restore_value: True
    initial_value: 0.0
    entity_category: "Config"

 # Temperature Probes 1
  - platform: dallas
    id: temp_1
    icon: mdi:thermometer-lines
    index: 0
    name: "Temperature"
    filters:
      - calibrate_linear:
          method: least_squares
          datapoints:
            - 0.0 -> id(cal_0).state
            - 100.0 -> !lambda 'id(cal_100).state';
```

Closed 2024-06-12.

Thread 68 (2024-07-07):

Aquapi bootilooping with factory image

kiguy2052, 2024-07-07:
**Describe the bug**
After flashing a fresh image using the default yaml, the device reboots immediately upon finishing setup.

**To Reproduce**
Not sure if reproducible

**Expected behavior**
No bootloop obvs

**Screenshots**
[logs (1).txt](https://github.com/user-attachments/files/16120366/logs.1.txt)
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

 - OS: ESP32
 - Browser: Flashing with esphome web in Chrome

**Additional context**
Tried with and without api: section commented out, it seems to be having some issue starting the api but otherwise I'm stumped

kiguy2052, 2024-07-07:
OK, I was able to find some new information and potentially reproduce the issue. I started by downloading the most recent release on the github( aquapi-esp32.factory.bin) and flashing it. I join the AP, configure it to use my guest network, and let it connect. All looks good according to the logs:
[logs (3).txt](https://github.com/user-attachments/files/16120430/logs.3.txt)

Then, I attempt to adopt it into ESPHome, which is where things go sideways. Immediately after esphome finishes uploading the api config, the bootloop begins occurring:
SC:
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
Logs:
[logs (4).txt](https://github.com/user-attachments/files/16120446/logs.4.txt)

Any ideas what might be causing this? Is anyone else able to reproduce?

TheRealFalseReality, 2024-07-07:
Hmm, try doing it with `api:` defined, that allows it to connect to Home Assistant, it may reboot every 15 mins without connecting to an API. As for the ESPHome reboot, not sure. Try doing it without any pins connected to the ESP device, perhaps something is messing with the pins....
Without anything connected, add these substitutions to the yaml so the logs aren't as cluttered with components that are not actually connected.
```
substitutions:
  update_ph: "never"
  update_ec: "never"
  update_do: "never"
  update_rtd: "never"
  update_pmp_1: "never" # Red
  update_pmp_2: "never" # Green
  update_pmp_3: "never" # White
  update_pmp_4: "never" # Orange
  update_pmp_5: "never" # Yellow
  update_pmp_6: "never" # Blue
  update_hum: "never"
  update_co2: "never"
  update_orp: "never"
  update_button_co2: "365days"
  update_button_ec: "365days"
  update_button_hum: "365days"
  ```

https://github.com/TheRealFalseReality/aquapi/wiki/Substitutions

TheRealFalseReality, 2024-07-07:
You can also try adding packages, one at time. I have it all split up
In your yaml, try this:
```
packages:
  TheRealFalseReality.aquapi/common:
    url: https://github.com/TheRealFalseReality/aquapi
    ref: main
    file: common/device_base_common.yaml
    refresh: 1s
  TheRealFalseReality.aquapi/esp32:
    url: https://github.com/TheRealFalseReality/aquapi
    ref: main
    file: common/device_base.yaml
    refresh: 1s
```

This is just the packages that allow the ESP32 to boot properly, no other components activated.

TheRealFalseReality, 2024-07-07:
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

replace the existing `packages` declaration.

kiguy2052, 2024-07-07:
Alright, that stops it from bootlooping, and it is able to show basic info in HA. Adding more yamls in reveals the issue may be the ota_https package. Here's my yaml:
https://pastebin.com/S65ck3pi
and the logs:
[logs (6).txt](https://github.com/user-attachments/files/16120751/logs.6.txt)
I suspect having one pump on the multiconnector might be causing issues, so I'm goingn to try the inital default yaml setup without the multi-connector and return with results. Thank you for your quick reply!

TheRealFalseReality, 2024-07-07:
Ok, lemme know. The `ota_https` is new, but works for me in testing. It's really only meant for AquaPi Firmware updates so I may need to remove it if it has issues.

kiguy2052, 2024-07-07:
Yep, it appears to be the ota_https. Here's the yaml I'm running, with everything(I think) except ota_https, and it doesn't bootloop:
https://pastebin.com/fvh9uviN
and here's the logs
[logs_aquapi-a9eef8_logs.txt](https://github.com/user-attachments/files/16121078/logs_aquapi-a9eef8_logs.txt)
I remember seeing a bug report(on the esphome github i think) about devices bootlooping when loading wifi libraries before ota. something about ota lacking wireless as a requirement. couldn't find it when I went back through my history, but it could be somewhere to start

TheRealFalseReality, 2024-07-08:
Ok, and I think I read somewhere having duplicate `ota:` in packages can cause issues. I simplified it, and made sure `ota:` is before `wifi:`. I updated it with some changes to `2024.6.4` if you wanna try that out.

kiguy2052, 2024-07-08:
the aquapi does not boot after installing the updated image. For whatever reason, my camera also using your repository is booting just fine. i'm wondering if it could be the order of these in the yaml?
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
camera yaml:
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
Maybe moving id: under icon: to match the camera config will make it work?

kiguy2052, 2024-07-08:
shoot, just noticed the app_version: "2024.6.4". I'm using esphome 2024.6.6. might be important lol🤦‍♂️

TheRealFalseReality, 2024-07-08:
no the `2024.6.4` is for the latest AquaPi

TheRealFalseReality, 2024-07-08:
try building it without the ota_httpa entirely, I created a branch that removes that, and only that.

```
packages:
  TheRealFalseReality.aquapi:
    url: https://github.com/TheRealFalseReality/aquapi
    ref: test-ota
    file: aquapi_config.yaml
    refresh: 1s
```

kiguy2052, 2024-07-08:
That works! Thanks for making that build!

kiguy2052, 2024-07-08:
OK, after running into the exact same issue with my other aquapi unrelated esphome devices, i found the issue. If it doesn't have internet, it will reboot after loading the ota, bootlooping it. This wasn't the case on previous versions, so I had them all on a cut off network. Throwing them on a vlan with internet let me use the normal version immediately. Any idea where I would report this further up the chain? Maybe the esphome github?

TheRealFalseReality, 2024-07-08:
Hmm, so you need internet otherwise the device just reboots? A little annoying. I do like the update sensor but maybe I will just keep a branch without ota_https in the meantime.

kiguy2052, 2024-07-08:
It's incredibly annoying. After further testing, I can confirm that if they don't have internet access, installing anything with ota_https will result in that device looping until it gets access. Once it can boot with internet, it seem to be fine, even surviving power cycling after the initial install is done with internet. Thanks for helping me work through this!

TheRealFalseReality, 2024-07-08:
No worries! I recently tested the ota_http and it worked fine, but it completely reset the device 100% including wifi credentials., not the intended results I wanted. I removed the feature entirely for now and is active in the main branch.

Closed 2024-07-08.

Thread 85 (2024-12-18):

Gerber Files

Ratief, 2024-12-18:
**Is your feature request related to a problem? Please describe.**
A clear and concise description of what the problem is. Ex. I'm always frustrated when [...]
It seems that the gerber files for the circuit board are missing. Is this project closed hardware?

**Describe the solution you'd like**
A clear and concise description of what you want to happen.
To have the gerber files added to the repo.

**Describe alternatives you've considered**
A clear and concise description of any alternative solutions or features you've considered.

**Additional context**
Add any other context or screenshots about the feature request here.

TheRealFalseReality, 2024-12-28:
Those I may not add as I somewhat consider the hardware proprietary. You are free create and use (not sell) your own boards using my design, but if I supply the manufacturing supplies, that's one step removed from someone creating their own boards to use. The software is open-sourced but the specific circuit-board is something I created for my product that I want to sell. I do sell the board ONLY for about $50 if you were interested.

Closed 2024-12-28.

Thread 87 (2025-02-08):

Wireless Signal UOM incorrect

DaveCBr, 2025-02-08:
**Describe the bug**
2025-02-08 10:53:11.282 WARNING (MainThread) [homeassistant.components.sensor] Entity sensor.aquapi_wifi_signal_strength (<class 'homeassistant.components.esphome.sensor.EsphomeSensor'>) is using native unit of measurement '%' which is not a valid unit for the device class ('signal_strength') it is using; expected one of ['dB', 'dBm']; Please update your configuration if your entity is manually configured, otherwise create a bug report at https://github.com/home-assistant/core/issues?q=is%3Aopen+is%3Aissue+label%3A%22integration%3A+esphome%22

**To Reproduce**
Steps to reproduce the behavior:
Noticed on HA restart and also recurring warning in HA Logs

**Expected behavior**
Change the UOM for wireless signal strength

**HA Information**
Core 2025.2.1
Supervisor 2025.02.0
Operating System 14.2
Frontend 20250205.0

**Additional context**
Firmware: 25.2 (ESPHome 2024.12.4)

TheRealFalseReality, 2025-02-08:
Yes this is a thing that will popup in HA. The WiFi Signal Strength is a copy of WiFi Signal dB (which is disabled by default), with the relevant conversaion. I believe HA still thinks this should be in db, so it flags it. It is safe to ignore. You can either either or both sensors in any case.

Closed 2025-02-08.

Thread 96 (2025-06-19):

install warning

m-f-g, 2025-06-19:
Hello,

i installed the factory file to a fresh and clean esp32.
i got this warning:

/config/esphome/common/device_base.yaml: In function 'void setup()':
/config/esphome/common/device_base.yaml:270:39: warning: conversion from 'long long unsigned int' to 'uint32_t' {aka 'unsigned int'} changes value from '31536000000' to '1471228928' [-Woverflow]
/config/esphome/common/aquapi.yaml:45:31: warning: conversion from 'long long unsigned int' to 'uint32_t' {aka 'unsigned int'} changes value from '31536000000' to '1471228928' [-Woverflow]

i could not find the solution, maybe you can help me out ...

bg
Michael

TheRealFalseReality, 2025-06-19:
Are you compiling this on a Windows? That error pops up when using ESPHome builder on Windows, at least, for me. I normally compile on my Windows as it is faster, but when I do compile firmware on my Linux, Home Assistant setup, its ok, no errors. I believe it's just a way Windows tries to convert a specific integer. But I have had no issues with any firmware compiled on Windows.

TheRealFalseReality, 2025-06-23:
Hmm, I'll try to reproduce the issue, I've only ever seen it on my Windows. In any case, it is benign.

Closed 2025-09-29.

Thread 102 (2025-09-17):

✨ Set up Copilot instructions

TheRealFalseReality, 2025-09-17:
Configure instructions for this repository as documented in [Best practices for Copilot coding agent in your repository](https://gh.io/copilot-coding-agent-tips).

<Onboard this repo>

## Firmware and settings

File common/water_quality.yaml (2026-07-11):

substitutions:
  sorting_group_water_quality: '20'

  # Change these to 'wq_dummy_sensor' or 'wq_dummy_binary' if you completely 
  # remove a package from your build to prevent C++ compile errors.
  wq_ph_sensor_id: ph_ezo
  wq_orp_sensor_id: orp_ezo
  wq_do_sensor_id: do_ezo
  wq_ec_sensor_id: ec_ezo
  wq_temp_sensor_id: temp_1
  wq_ideal_temp_id: ideal_temp
  
# --- SCORING PARAMETERS ---
  wq_ph_score_deviation_multiplier: '25.0'
  wq_ph_good_offset_low: '0.3'
  wq_ph_good_offset_high: '0.4'
  wq_ph_alert_offset_low: '0.8'
  wq_ph_alert_offset_high: '1.4'
  wq_orp_excellent_offset: '150'
  wq_orp_alert_offset: '100'
  wq_orp_score_max: '400'
  wq_do_score_deviation_multiplier: '15.0'
  wq_do_good_offset: '1.0'
  wq_do_alert_offset: '2.5'
  wq_ec_score_deviation_multiplier: '0.05'
  wq_ec_good_offset: '200'
  wq_ec_alert_offset: '500'

# --- SCORING WEIGHTS ---
  wq_ph_score_weight: '1.0'
  wq_orp_score_weight: '1.0'
  wq_do_score_weight: '1.0'
  wq_ec_score_weight: '1.0'
  wq_temp_score_weight: '0.5'

web_server:
  sorting_groups:
    - id: sorting_group_water_quality
      name: "Water Quality"
      sorting_weight: ${sorting_group_water_quality}

text_sensor:
  - platform: template
    name: "Water Quality"
    id: water_quality
    icon: mdi:water-check
    update_interval: 60s
    lambda: |-
      int status_score = -1; // -1=Unknown, 0=Excellent, 1=Good, 2=Caution, 3=Alert
      
      // --- pH Check ---
      if (id(${wq_ph_sensor_id}).has_state() && !isnan(id(${wq_ph_sensor_id}).state)) {
        float val = id(${wq_ph_sensor_id}).state;
        float low = id(ph_ideal_low).state;
        float high = id(ph_ideal_high).state;
        if (val < low - ${wq_ph_alert_offset_low} || val > high + ${wq_ph_alert_offset_high}) status_score = std::max(status_score, 3);
        else if (val < low - ${wq_ph_good_offset_low} || val > high + ${wq_ph_good_offset_high}) status_score = std::max(status_score, 2);
        else if (val >= low && val <= high) status_score = std::max(status_score, 0);
        else status_score = std::max(status_score, 1);
      }

      // --- ORP Check ---
      if (id(${wq_orp_sensor_id}).has_state() && !isnan(id(${wq_orp_sensor_id}).state)) {
        float val = id(${wq_orp_sensor_id}).state;
        float min_good = id(orp_min_good).state;
        float alert = fmaxf(0.0f, min_good - ${wq_orp_alert_offset});
        if (val < alert) status_score = std::max(status_score, 3);
        else if (val < min_good) status_score = std::max(status_score, 2);
        else if (val >= min_good + ${wq_orp_excellent_offset}) status_score = std::max(status_score, 0);
        else status_score = std::max(status_score, 1);
      }

      // --- DO Check ---
      if (id(${wq_do_sensor_id}).has_state() && !isnan(id(${wq_do_sensor_id}).state)) {
        float val = id(${wq_do_sensor_id}).state;
        float low = id(do_ideal_low).state;
        float high = id(do_ideal_high).state;
        if (val < low - ${wq_do_alert_offset} || val > high + ${wq_do_alert_offset}) status_score = std::max(status_score, 3);
        else if (val < low - ${wq_do_good_offset} || val > high + ${wq_do_good_offset}) status_score = std::max(status_score, 2);
        else if (val >= low && val <= high) status_score = std::max(status_score, 0);
        else status_score = std::max(status_score, 1);
      }

      // --- EC Check ---
      if (id(${wq_ec_sensor_id}).has_state() && !isnan(id(${wq_ec_sensor_id}).state)) {
        float val = id(${wq_ec_sensor_id}).state;
        float low = id(ec_ideal_low).state;
        float high = id(ec_ideal_high).state;
        if (val < low - ${wq_ec_alert_offset} || val > high + ${wq_ec_alert_offset}) status_score = std::max(status_score, 3);
        else if (val < low - ${wq_ec_good_offset} || val > high + ${wq_ec_good_offset}) status_score = std::max(status_score, 2);
        else if (val >= low && val <= high) status_score = std::max(status_score, 0);
        else status_score = std::max(status_score, 1);
      }

      // --- Temp Check ---
      if (id(${wq_ideal_temp_id}).has_state()) {
        bool temp_ok = id(${wq_ideal_temp_id}).state;
        if (!temp_ok) status_score = std::max(status_score, 2); // Triggers caution if temp is bad
        else status_score = std::max(status_score, 0);
      }

      // Return Final Status
      if (status_score == 3) return {"Alert"};
      if (status_score == 2) return {"Caution"};
      if (status_score == 1) return {"Good"};
      if (status_score == 0) return {"Excellent"};
      return {"Unknown"};
    on_value:
      then:
        - lambda: |-
            ESP_LOGI("water_quality", "Water Quality Status Updated: %s", x.c_str());
    web_server:
      sorting_group_id: sorting_group_water_quality
      sorting_weight: 10
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

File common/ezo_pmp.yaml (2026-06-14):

---
substitutions:
  # PMP circuit
  addPMP_white: "103"  # White
  update_pmp_white: "60s"

  sorting_group_pump_white_weight: '80'

web_server:
  sorting_groups:
    - id: sorting_group_pump_white
      name: "Pump - White"
      sorting_weight: ${sorting_group_pump_white_weight}

ezo_pmp:
  - id: ezo_pump_white
    address: ${addPMP_white}
    update_interval: "${update_pmp_white}"

api:
  actions:
    - action: pump_white_dose_volume
      variables:
        dose_volume: float
      then:
        - ezo_pmp.dose_volume:
            id: ezo_pump_white
            volume: !lambda 'return dose_volume;'
    - action: pump_white_dose_volume_time
      variables:
        dose_volume: float
        dose_time: float
      then:
        - ezo_pmp.dose_volume_over_time:
            id: ezo_pump_white
            volume: !lambda |-
              return dose_volume;
            duration: !lambda |-
              return dose_time;
    - action: pump_white_dose_flow_rate_time
      variables:
        dose_rate: float
        dose_time: float
      then:
        - ezo_pmp.dose_with_constant_flow_rate:
            id: ezo_pump_white
            volume_per_minute: !lambda |-
              return dose_rate;
            duration: !lambda |-
              return dose_time;
    - action: pump_white_dose_set_calibration
      variables:
        actual_volume: float
      then:
        - ezo_pmp.set_calibration_volume:
            id: ezo_pump_white
            volume: !lambda |-
              return actual_volume;
    - action: pump_white_change_address
      variables:
        address: int
      then:
        - ezo_pmp.change_i2c_address:
            id: ezo_pump_white
            address: !lambda |-
              return address;

sensor:
  - platform: ezo_pmp
    id: ezo_pump_white
    current_volume_dosed:
      id: current_volume_dosed
      name: Pump White - Current Volume Dosed
      disabled_by_default: true
      icon: mdi:cube-scan
      device_class: 'volume'
      unit_of_measurement: 'mL'
      state_class: total
      web_server:
        sorting_group_id: sorting_group_pump_white
  - platform: ezo_pmp
    id: ezo_pump_white
    total_volume_dosed:
      id: total_volume_dosed
      name: Pump White - Total Volume Dosed
      icon: mdi:timer-sand-empty
      device_class: 'volume'
      unit_of_measurement: 'mL'
      disabled_by_default: true
      web_server:
        sorting_group_id: sorting_group_pump_white
  - platform: ezo_pmp
    id: ezo_pump_white
    absolute_total_volume_dosed:
      id: absolute_total_volume_dosed
      disabled_by_default: true
      name: Pump White - Absolute Total Volume Dosed
      icon: mdi:timer-sand-full
      device_class: 'volume'
      state_class: total
      unit_of_measurement: 'mL'
      web_server:
        sorting_group_id: sorting_group_pump_white
  - platform: ezo_pmp
    id: ezo_pump_white
    last_volume_requested:
      id: last_volume_requested
      name: Pump White - Last Volume Requested
      icon: mdi:history
      disabled_by_default: true
      device_class: 'volume'
      state_class: total
      unit_of_measurement: 'mL'
      web_server:
        sorting_group_id: sorting_group_pump_white
  - platform: ezo_pmp
    id: ezo_pump_white
    max_flow_rate:
      id: max_flow_rate
      name: Pump White - Max Volume-Time Flow Rate
      icon: mdi:car-speed-limiter
      disabled_by_default: true
      unit_of_measurement: 'mL/min'
      web_server:
        sorting_group_id: sorting_group_pump_white
  - platform: ezo_pmp
    id: ezo_pump_white
    pump_voltage:
      id: pump_white_voltage
      name: Pump White - Voltage
      icon: mdi:lightning-bolt-circle
      disabled_by_default: true
      device_class: 'voltage'
      web_server:
        sorting_group_id: sorting_group_pump_white

binary_sensor:
  - platform: ezo_pmp
    id: ezo_pump_white
    pump_state:
      id: pump_white_state
      name: Pump White - State
      disabled_by_default: true
      icon: mdi:pump
      web_server:
        sorting_group_id: sorting_group_pump_white
  - platform: ezo_pmp
    id: ezo_pump_white
    is_paused:
      id: is_paused
      name: Pump White - Paused Status
      disabled_by_default: true
      icon: mdi:pause
      web_server:
        sorting_group_id: sorting_group_pump_white

text_sensor:
  - platform: ezo_pmp
    id: ezo_pump_white
    dosing_mode:
      id: dosing_mode
      name: Pump White - Dosing Mode
      disabled_by_default: true
      icon: mdi:auto-mode
      web_server:
        sorting_group_id: sorting_group_pump_white
  - platform: ezo_pmp
    id: ezo_pump_white
    calibration_status:
      id: calibration_status
      name: Pump White - Calibration Status
      disabled_by_default: true
      icon: mdi:tape-measure
      web_server:
        sorting_group_id: sorting_group_pump_white
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

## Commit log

2023-06-16 comment out dry
    [calibration_ec.yaml]
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2023-06-19 add datasheets
    [calibration_do.yaml, calibration_ec.yaml, calibration_ph.yaml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]
2023-06-21 added/removed verbose logging
    [calibration_aquapi_config.yaml, calibration_do.yaml, calibration_ec.yaml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]
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2023-07-29 Update aquapi_config.yaml
    Changed Water Level sensor update interval from 60s to 10s
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2023-08-10 Calibration Updates
    [aquapi-calibration-all.yaml, calibration_aquapi_config.yaml, calibration_do.yaml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]
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2023-08-19 added calibration configs
    [aquapi-calibration-all.yaml, calibration_do.yaml, calibration_ec.yaml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]
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2023-08-28 Update aquapi_config.yaml
    removed SSID sensor as GitHub actions will not build with it
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2023-10-19 STL
    STL models added
    [AquaPi Case v35.stl, AquaPi Case v36 - Lid.stl, AquaPi Case v39 - Plug.stl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]
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2023-11-12 STL updates
    [AquaPi Case v35.stl, AquaPi Case v36 - Lid.stl, AquaPi Case v43- IO Covers.3mf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]
2023-11-17 v1.3 EZO configs reworked
    Added commands and EC EZO outputs
    [calibration_ec.yaml]
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2023-11-22 Update temperature_dallas.yaml
    name fix
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2024-02-24 Revert "updates"
    This reverts commit 56d05d3c226f2d08eb0a8a1ccac951c6c5225765.
    [ezo_pmp.yaml]
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2024-02-26 Moved Files
    [AquaPi Case v39 - Plug.stl, AquaPi Case v43- IO Cover.stl, AquaPi Case v43- IO Covers.3mf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]
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2024-04-09 fix typos
    Fixed typos in Calibration Commands
2024-05-06 Blueprints added
    [ec_calibrate_aquapi.yaml, ph_calibrate_aquapi.yaml]
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2024-06-20 Revert "Update device_base_camera.yaml"
    This reverts commit 861b9b32d405b1a32de53c51e63a39cda5f51083.
2024-06-24 leak sensor support
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2024-06-26 pin fix
2024-06-27 Test camera (#65)
    * simplified
    * updates
    * updates
    * updates
    * Update aquapi_camera_config.yaml
    * Update device_base_common.yaml
    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
2024-07-01 Test (#67)
    * Changes to be committed:
    modified: aquapi_config.yaml
    modified: common/device_base.yaml
    new file: common/dht.yaml
    modified: common/ezo_pmp_duo.yaml
    new file: common/ir_receiver.yaml
    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
2024-07-07 Test - ota_https (#69)
    modified: common/ezo_commands.yaml
    * blueprints updated
    * blueprints updated
    * name update
    * Update aquarium_ato_aquapi.yaml
    * ota changes
    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
2024-07-08 Test ota (#70)
    * Update aquapi_config.yaml
    * modified: common/device_base_common.yaml
    modified: common/ota_https.yaml
    * Changes not staged for commit:
    modified: aquapi_camera_config.yaml
    modified: common/ota_https.yaml
    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
2024-07-20 Test temp (#71)
    * additional temperature config added
    * changes
    * Update temperature_dallas_2.yaml
    * Update temperature_dallas_2.yaml
    * Update temperature_dallas_2.yaml
    * Update temperature_dallas_2.yaml
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2024-07-30 stls updated
    [AquaPi Case - Base v45.stl, AquaPi Case - Lid v45.stl, AquaPi Case v39 - Plug.stl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]
2024-07-30 name change
    [AquaPi Case - Base v45.stl, AquaPi Case - Lid v45.stl, Handle v2.stl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]
2024-07-31 cam models added
    [BallMount - ZipTie v9.stl, BallMount v9.stl, esp32Cam - Case v32.stl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]
2024-08-01 Create AquaPi Case - CablePlug v45.stl
    [AquaPi Case - CablePlug v45.stl]
2024-08-10 EZO Case stl added
    [EZO Board Case v27.stl, EZO Board Lid 27.stl]
2024-08-10 folder move
    [EZO Board Case v27.stl, EZO Board Lid 27.stl]
2024-08-10 folder rename
    [EZO Board Case v27.stl, EZO Board Lid 27.stl]
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2024-11-25 Test web server v3 (#78)
    * Update device_base.yaml
    updated to web server v3
    * Update temperature_dallas.yaml
    added sorting group
    * sorting groups
    * Update device_base.yaml
    * Update device_base.yaml
    * sort group
    * sorting groups
    * syntax
    * weights updated
    * test
    * sorting fixes
    * Update device_base.yaml
    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
2024-11-26 Do and more (#77)
    * fixes
    * Update ezo_pmp.yaml
    * Update ezo_pmp_duo.yaml
    * sort updates
    temp_2 updates
    * update
    * sorting added
    * sorting added
    * soerting added
    * sorting added
    *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
2024-11-28 ota fixes
    [AquaPi Case - Base v45.stl, AquaPi Case - Base v53.stl, AquaPi Case - CablePlug v45.stl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]
2024-11-30 Update ezo_do.yaml
    fixes to sensor
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2025-01-13 added stl models
    [AquaPi Case & IO.3mf, AquaPi Mount.3mf, AquaPi Pump Case v25.stl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]
2025-01-13 folder name change
    [AquaPi Pump Case v25.stl, AquaPi Pump Case.3mf, AquaPi Pump Lid v25.stl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]
2025-02-05 more actions added
    Custom EZO command action.
    I2C address change (not tested).
2025-02-19 group weights fixes for additional pumps
    [ezo_pmp_orange.yaml, ezo_pmp_yellow.yaml]
2025-02-27 Fix logo display in README.md (#91)
    * Update README.md
    Fixed logo link
    * Update README.md
    Inserted relative links to "assests" folder. Note misspelling not corrected.
    * Update README.md
    Revert static links to private user content
    * Update README.md
    Reverted Made for ESPHome
2025-02-27 assests renamed to assets
    [AquaPi Case & IO.3mf, AquaPi Case - Base v53.stl, AquaPi Case - IO v54.3mf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]
2025-03-13 fixes to IDs and others
    [ezo_pmp_blue.yaml, ezo_pmp_orange.yaml, ezo_pmp_yellow.yaml]
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2025-07-03 Set sensors and controls to disabled by default
    Added 'disabled_by_default: true' to various sensors, binary sensors, text sensors, numbers, and buttons in ezo_co2.yaml, ezo_pmp.yaml, and ezo_pmp_duo.yaml to prevent them from being enabled automatically. Also bumped app_version to 25.6.2 in aquapi_config.yaml.
    [ezo_pmp.yaml, ezo_pmp_duo.yaml]
2025-08-07 Update binary sensor pin naming and IDs
    Standardized substitution and sensor IDs in binary.yaml and binary_input.yaml for clarity. Updated sensor names and pin references to maintain consistency across configuration files.
2025-08-07 Fix binary sensor pin variable names in YAML files
    Corrected the pin number variable references in binary.yaml and binary_input.yaml to use the appropriate variable names. This ensures the correct pins are assigned to each binary sensor.
2025-08-07 Update binary input pin assignments
    Changed binary_pin_2 from 34 to 18 and binary_pin_3 from 35 to 19 to reflect new hardware configuration.
2025-08-07 Add binary sensors 4 and 5 to configuration
    Introduced two new GPIO-based binary sensors (binary_pin_4 and binary_pin_5) with corresponding pin assignments, filters, and web server sorting group. This extends the input capabilities for additio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
2025-08-07 Add support for binary_pin_6 in binary_input.yaml
    Introduces configuration for a new GPIO binary sensor (binary_pin_6) on pin 23, including web server integration and filtering. This expands the number of supported binary inputs.
2026-01-25 Add device_class for Leak Sensor in binary.yaml
2026-01-28 Replace .state with .current_option() in EZO YAMLs (#110)
    * Replace .state with .current_option() in EZO YAMLs
    Updated all EZO sensor YAML files to use the .current_option() method instead of .state for select command checks in lambda actions. This change ensures compatibility with updated select component APIs and improves code reliability.
    * Comment out I2C device checks in EZO sensor configs
    Disabled the I2C device presence checks and related diagnostic sensor in device_base.yaml and all EZO sensor YAML files. This simplifies button actions by removing address probing and warning logs, likely to improve reliability or reduce unnecessary I2C traffic.
2026-02-02 Use 'Volume-Time' wording for pump labels
    Replace 'Volume/Time' with 'Volume-Time' in pump-related entity names across ezo_pmp YAMLs for consistent labeling and phrasing. Updated files: common/ezo_pmp.yaml, common/ezo_pmp_blue.yaml, common/ezo_pmp_duo.yaml, common/ezo_pmp_orange.yaml, common/ezo_pmp_yellow.yaml. Also add archive/aquapi_config copy.yaml to archive a snapshot of the Aquapi package includes and app_version.
    [ezo_pmp.yaml, ezo_pmp_blue.yaml, ezo_pmp_duo.yaml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]
2026-02-03 Implement robust I2C sensor detection and debugging standards (#111)
    * Initial plan
    * Add comprehensive debug and I2C sensor detection modules
    * Fix I2C detection binary sensors and validate configuration
    * Address code review feedback - DRY principle and code simplification
    * Use 'Volume-Time' wording for pump labels (#112)
    Replace 'Volume/Time' with 'Volume-Time' in pump-related entity names across ezo_pmp Y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
    [AquaPi Case & IO.3mf, AquaPi Case - Base v53.stl, AquaPi Case - Base v58.stl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]
2026-02-03 Enable I2C presence checks for EZO sensors
    Uncomment and enable I2C presence checks in EZO sensor button handlers. Each lambda now declares a byte error, calls Wire.beginTransmission/endTransmission to detect the device, sends the read command when the device responds, and logs a warning when no device is detected. Changes applied to common/ezo_co2.yaml, common/ezo_do.yaml, common/ezo_ec.yaml, common/ezo_hum.yaml, common/ezo_orp.yaml, and common/ezo_ph.yaml.
2026-02-03 Migrate EZO sensors from Wire library to ESPHome I2C component (#113) (#115)
    * Migrate pH, EC, HUM, ORP, DO, CO2 sensors from Wire to ESPHome I2C component
    ---------
    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
2026-02-03 Add helpful error messages for missing EZO sensors (#114)
    * Add helpful error messages for missing EZO sensors
    * Add button-based updates with detection checks for pH, ORP, RTD sensors
    * Add documentation for handling EZO sensor read errors
    * Address code review feedback: reduce delay and fix capitalization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
2026-02-03 Extract app version and sensor to separate file
    Move the App Version substitution and the AquaPi Version template sensor out of common/aquapi.yaml into a new common/aquapi_app_version.yaml to modularize the configuration. common/aquapi.yaml now in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
2026-02-04 Add index-based Dallas temperature configuration for multiple sensors (#117)
    * Add index-based Dallas temperature configuration for plug-and-play multiple sensors
    * Update README with multiple temperature sensor support reference
    * Fix consistency issues: spacing, icons, and naming in temperature_dallas_index.yaml
    * Use temperature_dallas_index include; move README
    Update aquapi_config.yaml to u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
    [temperature_dallas_index.yaml]
2026-02-04 Update README and remove Dallas index readme
    Add brief descriptors to the top wiki links in README and replace the plain DS18B20 mention with a link to the Dallas Temperature Sensor wiki page for more detail. Remove TEMPERATURE_DALLAS_INDEX_README.md (redundant/merged into the wiki) to avoid duplicated documentation.
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2026-03-10 factory reset commands added to EZO circuits
2026-03-22 feat: add Legacy water level sensor firmware variant and install button (#123)
    Agent-Logs-Url: https://github.com/TheRealFalseReality/aquapi/sessions/238f8898-a45f-4e03-862f-f2b2c3f2ecea
2026-03-22 fix: parameterize OTA URLs and dashboard import for legacy config (#124)
    - Add ota_firmware_name substitution to common/ota_https.yaml (default: aquapi)
    so legacy config can point to aquapi-legacy.manifest.json / aquapi-legacy-esp32.ota.bin
    - Add package_import_url substitution to common/aquapi.yaml so legacy config
    can point dashboard_import at aquapi_config_legacy.yaml@main
    - Override project_name, package_import_url, and ota_firmware_name in
    aquapi_config_legacy.yaml for correct legacy identity and firmware URLs
    - Add both new substitutions to common/substitutions.yaml defaults
    Agent-Logs-Url: https://github.com/TheRealFalseReality/aquapi/sessions/2409f9a3-c9ea-49d6-8b59-10af2785b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
2026-03-22 Revert to a598d71: undo legacy water level variant and OTA URL parameterization (#125)
    * Revert "fix: parameterize OTA URLs and dashboard import for legacy config (#124)"
    This reverts commit 9a24000f810a9ebcb5b40b0cf99a1c56f216d970.
    * Revert "feat: add Legacy water level sensor firmware variant and install button (#123)"
    This reverts commit 776af6e2b125a06766a15f1fdb5f382595ec697f.
    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
2026-06-14 fix(debug): replace Arduino ESP object and byte type with ESP-IDF equivalents (#136)
    * fix(debug): replace Arduino ESP/byte types with ESP-IDF equivalents
    * fix(debug): add ESP32-C2 and ESP32-C6 chip model cases
    * Update debug.yaml
    * Update debug.yaml
    added psram
    * Update debug.yaml
    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
2026-06-14 feat: add `custom_command` and parametrized `calibrate` actions to all EZO sensor probes (#135)
    * feat: add custom_command and calibrate actions to all EZO sensor probes
    * fix: change ec_calibrate_low/high variable type to float for decimal precision
    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
2026-06-14 Add leak alerting, water quality sensors, DO compensation automation, and EZO calibration state tracking (#140)
    * feat: add water quality and calibration tracking
    * refactor: clarify water quality thresholds
    * docs: clarify calibration and dependency behavior
    * Potential fix for pull request finding
    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
    [water_quality.yaml]
2026-06-14 Store Dallas temperature thresholds in Celsius (#138)
    * fix: store Dallas temperature thresholds in Celsius
    * Update i2c_detection.yaml
    removed I2C Bus Status text sensor
    * Update i2c_detection.yaml
    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
    [temperature_dallas_index.yaml]
2026-06-14 reworked Dallas sensors
2026-06-14 Fix EZO command dispatch fallthrough, parameterize I2C detection addresses, and correct EC/water-level metadata logic (#137)
    * fix: correct EZO command branching and sensor metadata mappings
    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
2026-06-14 Improve EZO command feedback, pump reverse-dose labels, and raw-value parsing safety (#139)
    * feat: improve EZO calibration and pump UX
    * fix: clean up pump volume comments
    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
    [ezo_pmp.yaml, ezo_pmp_blue.yaml]
2026-06-14 i2c fixes
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2026-06-17 Disable i2c_detection include in configs
    Comment out the i2c_detection include in aquapi_config.yaml and aquapi_config_optical.yaml so the common/i2c_detection.yaml package is not loaded at startup. This prevents automatic I2C detection (useful for devices without I2C or to reduce startup noise) while leaving the original lines for easy re-enabling.
2026-06-18 Do rework (#146)
    * Update ezo_do.yaml
    * Update ezo_do.yaml
    * Update ezo_do.yaml
    * Update ezo_rtd.yaml
    * Update ezo_rtd.yaml
    * Update ezo_rtd.yaml
    * Add °C to temperature names; remove Dallas file
    Make temperature units explicit by appending "°C" to various number entity names in common/ezo_rtd.yaml and common/temperature_dallas_index.yaml (e.g., "Temp. Cool" -> "Temp. Cool °C"). Also remove common/temperature_dallas.yaml (deleted) as part of cleanup.
    * Update ezo_rtd.yaml
    * Move water-quality number entities to sensor files
    Relocate the Water Quality configuration number entities into their respective sensor files for better modularity. Added template number entities for "Water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
    [temperature_dallas_index.yaml, water_quality.yaml]
2026-06-20 App version rework (#147)
    * app version rework
    * more
    * Create aquapi_app_version.yaml
    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
2026-07-11 Use substitution IDs in water quality checks
    Replaced hardcoded sensor IDs in the water quality range binary_sensor lambdas (pH, ORP, DO, EC) with existing substitution-based IDs. This makes the package consistent with its configurable substitutions and allows users to override sensor IDs without breaking in-range evaluations.
    [water_quality.yaml]
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2026-10-09 Fix manifest path for AquaPi Optical button
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2026-10-10 Log EZO circuit responses and add disabled-by-default "Find" command for EZO sensors (#158)
    * Apply remaining changes
    * Apply remaining changes
    * Undo last action
    * Remove stray pip wheels
    * logger responcces added
    * syntax fixes
    * Fix pump log lambdas: remove undeclared x, log command sent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
